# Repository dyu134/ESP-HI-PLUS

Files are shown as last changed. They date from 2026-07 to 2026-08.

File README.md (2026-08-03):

# ESP-HI-PLUS

An **AI-enabled voice assistant with on-screen interaction**, built around the **ESP32-S3-WROOM-1**. The board integrates a microphone, speaker amplifier, IMU, 2" IPS LCD, MicroSD card slot, and USB-C with on-board Li-ion battery charging, and exposes **two 5-pin magnetic pogo-pin connectors** for attaching various sub-modules. Designed for handheld and wearable applications that combine on-device conversational AI, audio capture/playback, display feedback, and motion sensing.

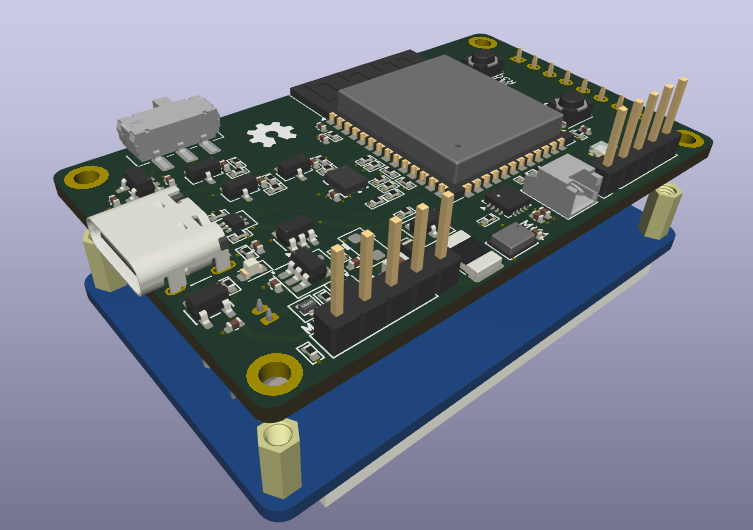
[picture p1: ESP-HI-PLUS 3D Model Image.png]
ESP-HI-PLUS 3D Model


## Features

### Core Compute

- **ESP32-S3-WROOM-1** (U2) — 32-bit dual-core LX7 MCU with Wi-Fi 4, BLE 5 (LE), and a rich peripheral set including I2S, I2C, SPI, and USB.

### Sensors

- **LSM6DSV16X** 6-axis IMU (U8) — 3-axis accelerometer + 3-axis gyroscope with I3C/I2C/SPI interface for motion tracking.
- **ICS-43434 I2S Microphone** (MK1) — digital MEMS microphone over I2S for audio capture.

### Audio Output

- **MAX98357A** Class-D I2S amplifier (U7) — drives an external speaker (LS1) with no required MCLK.
- **PicoBlade speaker connector** (LS1) for an off-board speaker.

### Power

- **USB-C input** (J1) with **USBLC6-2P6** ESD protection (D1/D7/D8).
- **TP4065** linear Li-ion/Li-Po charger (U5) — single-cell charging from USB.
- **TLV75733PDBV** 3.3 V LDO (U3) — system rail for the MCU and logic.
- **MAX40200AUK** ideal-diode OR-ing (U1, U6) — seamless USB / battery switching with low dropout.
- **PicoBlade battery connector** (BT1) for a single-cell Li-ion / Li-Po pack.
- **PMEG4010CEJ** Schottky diode (D5) and **MF-MSMF200** PTC fuse (F1) for input/battery protection.
- **SMF6.8CA** TVS diode (D6) for transient suppression.

### User Interface

- **[2" LCD header](https://www.waveshare.com/2inch-LCD-Module.htm)** (J2) — 2" IPS LCD display.
- **MicroSD Card Slot** (J5) — for local storage of audio, logs, or assets.
- **Two SKRPACE010 tactile pushbuttons** (SW1, SW2).
- **JS102011SAQN SPDT slide switch** (SW3).
- **WS2812B-2020** addressable RGB LED (D12), plus discrete status LEDs (D2 orange for battery charging, D4 red for USB power).
- **Two PR5L4015-5P-C-F magnetic pogo-pin connectors** (J3, J4) — 5-pin 2.54 mm headers that mate with **magnetic pogo-pin sub-modules** for snap-on expansion.

### Mounting

- Four M2 slim mounting holes (H1–H4).

## Sub-Module Identification

The ESP-HI-PLUS uses a two-stage detection system (analog ID resistor + I²C EEPROM metadata) to identify and configure attached sub-modules.

Detailed technical specifications for the identification protocol, class table, and EEPROM metadata can be found in the [Sub-modules directory](./Sub-modules/README.md).

## Available Sub-modules

- **[Desktop](./Sub-modules/Desktop/README.md)** — A desktop alarm clock and environment monitor featuring temperature, humidity, and presence sensing.

See the [Sub-modules directory](./Sub-modules/README.md) for technical specifications and the full list of supported classes.

## Repository Layout

```text
.
├── ESP-HI-PLUS.kicad_pro       # KiCad project file
├── ESP-HI-PLUS.kicad_sch       # Schematic
├── ESP-HI-PLUS.kicad_pcb       # PCB layout
├── Sub-modules/                # Snap-on expansion boards
│   └── Desktop/                # Desktop alarm clock / environment monitor
├── fp-lib-table                # Footprint library table
├── sym-lib-table               # Symbol library table
├── fabrication-toolkit-options.json
├── ESP-HI-PLUS Symbols/        # Project-local schematic symbols
├── ESP-HI-PLUS Footprints/     # Project-local footprint libraries (*.pretty)
├── ESP-HI-PLUS 3D Models/      # STEP models used by the 3D viewer
├── production/                 # Manufacturing outputs
    ├── bom.csv                 # Bill of materials
    ├── designators.csv         # Reference designators
    ├── positions.csv           # Pick-and-place positions
    ├── netlist.ipc             # IPC-D-356 netlist
    └── ESP-HI-PLUS_v1.17.zip   # Production archive (latest)
```

## Bill of Materials (summary)

| Refs | Description |
|---|---|
| U2 | ESP32-S3-WROOM-1 module |
| U3 | TLV75733PDBV — 3.3 V LDO |
| U5 | TP4065 — Li-ion charger |
| MK1 | ICS-43434 I2S microphone |
| U7 | MAX98357A — I2S Class-D amplifier |
| U8 | LSM6DSV16X — 6-axis IMU |
| U1, U6 | MAX40200AUK — ideal diode |
| D1/D7/D8 | USBLC6-2P6 — USB ESD TVS array |
| D12 | WS2812B-2020 — addressable RGB LED |
| J1 | USB-C receptacle |
| J2 | [2" IPS LCD connector](https://www.waveshare.com/2inch-LCD-Module.htm) |
| J3, J4 | Two 5-pin magnetic pogo-pin connectors (PR5L4015-5P-C-F) for sub-modules |
| J5 | MicroSD Card Slot (Hirose DM3AT) |
| SW1, SW2 | SKRPACE010 tactile pushbuttons |
| SW3 | JS102011SAQN SPDT slide switch |
| R28, R29 | 47 kΩ sub-module **AUX1/ID0** detection resistors (0402) — divider used for ADC class lookup |

See `production/bom.csv` for the full BOM with footprints and quantities.

## Getting Started

1. Open `ESP-HI-PLUS.kicad_pro` in KiCad 8 or later.
2. Review the schematic (`ESP-HI-PLUS.kicad_sch`) and PCB (`ESP-HI-PLUS.kicad_pcb`).
3. Re-generate fabrication outputs as needed (Gerbers, drill files, pick-and-place).
4. Flash the ESP32-S3 via the USB-C port using ESP-IDF or Arduino.

## Manufacturing Outputs

The `production/` folder contains ready-to-use outputs for the latest **v1.17** revision:

- **`bom.csv`** — bill of materials for sourcing.
- **`positions.csv`** — pick-and-place rotation/coordinates for SMT assembly.
- **`netlist.ipc`** — IPC-D-356 test netlist.
- **`ESP-HI-PLUS_v1.17.zip`** — full fabrication archive (Gerbers + drill included).

## License

License not specified. Add a `LICENSE` file if you intend to distribute this design.

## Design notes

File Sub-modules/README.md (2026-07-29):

# ESP-HI-PLUS Sub-modules

This directory contains various snap-on expansion boards for the **ESP-HI-PLUS** main board. These modules connect via the two 5-pin magnetic pogo-pin connectors and are automatically detected by the main board.

## List of Sub-modules

- **[Desktop](./Desktop/README.md)** — Desktop alarm clock and environment monitor. Features temperature/humidity sensing and presence detection.
- **[Portable](./Portable/README.MD)** — High-performance expansion board with STM32U5, USB-PD, and battery charging support.
- **[Robot](./Robot/README.md)** — Robotic actuator and sensing platform with RP2040, IMU, fuel gauge, and 4-channel servo control.

## Sub-Module Identification

The two 5-pin magnetic pogo-pin connectors (J3, J4) carry an analog ID line that lets the main board auto-detect **what class of sub-module** is attached before initializing it.

### How it works

1. **On the main board (ESP-HI-PLUS)**, a resistor divider is built around R28 (47 kΩ) and R29 (47 kΩ) tied to the 3.3 V rail and GND. With no sub-module attached, the divider midpoint sits at ~1.65 V (mid-supply) and is fed into an ESP32-S3 ADC channel.
2. **Before initializing any sub-board**, firmware reads that ADC voltage.
3. **On the sub-module**, an additional pull-up resistor `R_ID` is connected between the **AUX1/ID0** line and 3.3 V. The parallel combination with R28 shifts the divider voltage to a value that uniquely identifies the sub-module class.
4. The measured ADC voltage is matched against the table below to select the correct driver/configuration for the attached module.
5. **Once the class is known**, the main board reads the **I²C EEPROM** sitting on the sub-module through the shared I²C bus on the pogo connector. The EEPROM carries module-specific metadata (see below) that the firmware uses to finish initializing that particular sub-board variant correctly.

The two-stage lookup (cheap analog ID + rich digital metadata) lets many different sub-modules share the same physical connector and pinout while still being recognized, configured, and updated individually.

### Class Table

| Class | R_ID (sub-module pull-up) | ADC Voltage (V) | Class Type |
|---:|---:|---:|---|
| 0 | Open (no module) | 1.65 | No module attached |
| 1 | 953 kΩ | 1.63 | Actuator — Servo |
| 2 | 549 kΩ | 1.58 | Actuator — Stepper |
| 3 | 383 kΩ | 1.54 | Sensor — Environmental |
| 4 | 287 kΩ | 1.49 | Sensor — Mechanical |
| 5 | 226 kΩ | 1.43 | Audio — Speaker |
| 6 | 182 kΩ | 1.37 | Audio — Microphone |
| 7 | 154 kΩ | 1.31 | Display — Screen |
| 8 | 130 kΩ | 1.24 | Display — LED |
| 9 | 110 kΩ | 1.17 | Communication — 2.4 G |
| 10 | 95.3 kΩ | 1.11 | Communication — LoRA |
| 11 | 82.5 kΩ | 1.04 | Power — Battery |
| 12 | 71.5 kΩ | 0.97 | Power — Solar |
| 13 | 61.9 kΩ | 0.89 | User Defined 1 |
| 14 | 53.6 kΩ | 0.82 | User Defined 2 |
| 15 | 47.5 kΩ | 0.75 | User Defined 3 |
| 16–31 | — | — | Reserved |

Designing your own sub-module? Pick any standard E24 / E96 `R_ID` value from the table and add it from the ID line to 3.3 V on the sub-board — the main board will detect the class automatically on the next power-up.

### EEPROM metadata

The sub-module's I²C EEPROM exposes at minimum the following fields, which the main board reads via standard I²C reads (typically at the address indicated by the detected class, default `0x50` if unspecified):

| Offset | Size | Field | Description |
|---:|-----:|---|---|
| 0x00 | 4 | Magic Number | ASCII `"ESPM"` (0x45 0x53 0x50 0x4D) — sanity-check that an ESP-HI EEPROM is present |
| 0x04 | 1 | Class ID | Module-class number matching the class table above (little-endian `u8`) |
| 0x05 | 1 | Module ID | Module-class number matching the class table above (little-endian `u8`) |
| 0x06 | 1 | HW revision | Sub-board hardware revision (little-endian `u8`) |
| 0x07 | 2 | FW revision | Sub-board firmware revision (major.minor) (little-endian `u16`) |
| 0x09 | 1 | Protocol revision | Communication protocol revision (little-endian `u8`) |
| 0x0A | 1 | Power requirement | 0x00 = Self-powered, 0x01 = Requires 5V, 0x02 = Can charge |
| 0x0B | 2 | Max Current (mA)  | Maximum current draw (little-endian `u16`), default 500 mA |
| 0x0D | 2 | Min Voltage (mV)  | Minimum supply voltage (little-endian `u16`), default 4500 mV |
| 0x0F | 2 | Boot Delay | Number of milliseconds to delay after power-on (little-endian `u16`), default 100ms  |
| 0x11 | 4 | Capability Bitmask| Bitmask of capabilities defined below (little-endian `u32`) |
| 0x15 | 16 | Module Name | ASCII string (little-endian `u32`) |
| 0x25 | 16 | Serial Number | ASCII string (little-endian `u32`) |
| 0x35 | 198  | User Data | ASCII string (little-endian `u32`) |
| 0xFB | 4 | CRC32 | CRC32 of the rest of the EEPROM data (little-endian `u32`) |

If the magic bytes don't match or the CRC fails, the main board treats the EEPROM as missing/corrupt and falls back to the **class-only driver** selected from the table — letting older or unprogrammed sub-modules still function.

### Capability Bitmask

The 32-bit field at EEPROM offset `0x11` advertises the runtime capabilities of the attached sub-module. Each bit is enumerated below; **bits 8–31 are reserved** for future use and must be written as `0` by sub-module firmware.

| Bit | Name | Meaning |
|----:|---|---|
| 0 | Needs Calibration | Main module must send `CMD_CALIBRATE` before normal ops |
| 1 | Requires ACK | Main module must wait for `ACK` after every command |
| 2 | Asynchronous Data | Module sends unsolicited status reports |
| 3 | Supports Sleep | Module can enter sleep mode |
| 4 | Has Emergency Stop | Module can trigger an emergency stop |
| 5 | Supports OTA | Module can receive firmware updates from main |
| 6 | Has Battery Backup | Module has its own backup battery |
| 7 | Requires Bootloader Mode | Main must enter bootloader mode before firmware update |
| 8–31| Reserved | Reserved — must be `0` |

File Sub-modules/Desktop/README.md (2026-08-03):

# Desktop Sub-module

The **Desktop** sub-module is an environment-sensing and time-keeping expansion board for the **ESP-HI-PLUS**. It transforms the voice assistant into a desktop companion capable of monitoring room conditions and detecting human presence.

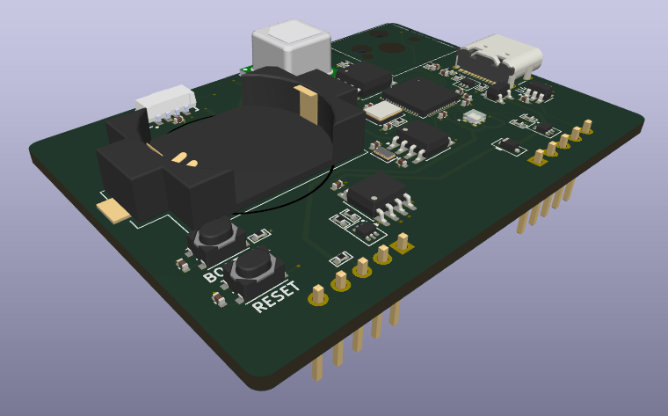
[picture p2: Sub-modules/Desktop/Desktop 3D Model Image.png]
Desktop 3D Model


## Features

### Core Compute

- **RP2040** (U3) — Dual-core ARM Cortex-M0+ microcontroller to handle local sensor processing and timing.
- **16 Mbit Flash** (U1) — Storage for RP2040 firmware.

### Environment Sensors

- **SHT4x** (U5) — High-accuracy relative humidity and temperature sensor.
- **STHS34PF80** (U6) — Infrared sensor for presence and motion detection.
- **VEML7700** (U7) — Ambient light sensor for automatic display brightness adjustment.

### Time Keeping

- **MCP79410** (U8) — I²C Real-Time Clock with SRAM and battery backup.
- **CR2032 Battery** (BT1) — Ensures the clock keeps time even when the main board is powered off.

### Identification & Metadata

The Desktop module follows the standard [ESP-HI-PLUS identification protocol](../README.md).

- **R_ID (383 kΩ)** — Identifies the module as **Class 3 (Sensor — Environmental)**.
- **AT24CS02** (U10) — 2 Kbit I²C EEPROM carrying module metadata and serial number.

#### EEPROM Metadata

| Offset | Size | Field | Value (Hex) | Value (Decoded) | Description |
| :---: | :----: | :--- | :---: | :--- | :--- |
| 0x00 | 4 | Magic Number | 45 53 50 4D | "ESPM" | ASCII sanity check |
| 0x04 | 1 | Class ID | 0x03 | 3 | Sensor - Environmental |
| 0x05 | 1 | Module ID | 0x01 | 1 | Desktop v1.17 |
| 0x06 | 1 | HW Revision | 0x01 | 1 | First PCB revision |
| 0x07 | 2 | FW Revision | 0x1101 | 1.17 | Major.Minor |
| 0x09 | 1 | Protocol Revision | 0x01 | 1 | Communication protocol v1 |
| 0x0A | 1 | Power Requirement | 0x00 | Self-powered | USB-C powered, no V_BUS needed |
| 0x0B | 2 | Max Current (mA) | 0x01F4 | 500 mA | Maximum draw (little-endian) |
| 0x0D | 2 | Min Voltage (mV) | 0x1194 | 4500 mV | Minimum supply voltage (little-endian) |
| 0x0F | 2 | Boot Delay (ms) | 0x0064 | 100 ms | Power-on delay (little-endian) |
| 0x11 | 4 | Capability Bitmask | 0x0000000D | — | Bits 0, 2, 3 enabled (see below) |
| 0x15 | 16 | Module Name | 44 65 73 6B... | "Desktop" | ASCII, null-terminated |
| 0x25 | 16 | Serial Number | 44 43 2D 30... | "DC-001-ABCD" | ASCII, null-terminated |
| 0x35 | 198 | User Data | — | — | Available for custom data |
| 0xFB | 4 | CRC32 | 0xXXXXXXXX | — | CRC32 of bytes 0x00–0xFA |

#### Capability Bitmask

**Value:** `0x0000000D` (Bits 0, 2, and 3 set)

| Bit | Value | Capability | Status |
| :---: | :---: | :--- | :--- |
| 0 | 0x01 | Needs Calibration | ✅ Enabled |
| 1 | 0x02 | Requires ACK | ❌ Disabled |
| 2 | 0x04 | Async Data | ✅ Enabled |
| 3 | 0x08 | Supports Sleep | ✅ Enabled |
| 4 | 0x10 | Has Emergency Stop | ❌ Disabled |
| 5 | 0x20 | Supports OTA | ❌ Disabled |
| 6 | 0x40 | Has Battery Backup | ❌ Disabled |
| 7 | 0x80 | Requires Bootloader Mode | ❌ Disabled |
| 8–31 | — | Reserved | — |

### User Interface & IO

- **WS2812B-2020** (D2) — Addressable RGB LED for status or mood lighting.
- **Tactile Switches** (SW1, SW3) — Reset and bootmode selection switching.
- **Snooze Button** (SW2) — **Kailh MX mechanical keyboard switch** (hotswap) for sleep mode activation.
- **USB-C Port** (J1) — For independent programming and powering of the RP2040.

## Integration

This module identifies itself as an environmental sensor class. The ESP-HI-PLUS main board can read data from the onboard sensors through commands to the RP2040 via UART through the magnetic pogo-pin connectors.

### Pinouts (Magnetic Pogo Connectors)

The Desktop module uses two 5-pin magnetic pogo-pin connectors to interface with the main board.

#### J2 (MAG1)

| Pin | Name | Description |
| --- | --- | --- |
| 1 | VMAIN  | 2-way power bus shared with main module |
| 2 | GND | Ground |
| 3 | UART RX| From main module for data transmission |
| 4 | UART TX| From main module for data transmission |
| 5 | EN | Main module control to enable/disable submodule power |

#### J3 (MAG2)

| Pin | Name | Description |
| --- | --- | --- |
| 1 | I2C SDA  | For reading module ID metadata EEPROM |
| 2 | I2C SCL  | For reading module ID metadata EEPROM |
| 3 | AUX1/ID0 | Hardware class identifier resistor |
| 4 | AUX2 | Auxiliary data pin (unused) |
| 5 | AUX3 | Auxiliary data pin (unused) |

## Repository Layout

```text
.
├── Desktop.kicad_pro           # KiCad project file
├── Desktop.kicad_sch           # Schematic
├── Desktop.kicad_pcb           # PCB layout
├── Desktop Symbols/            # Project-local schematic symbols
├── Desktop Footprints/         # Project-local footprint libraries
├── Desktop 3D Models/          # STEP models
└── production/                 # Manufacturing outputs
    ├── bom.csv                 # Bill of materials
    └── ESP-HI-PLUS_Desktop_Sub-module_v1.17.zip # Production archive (latest)
```

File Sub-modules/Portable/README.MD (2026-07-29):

# Portable Sub-module

The **Portable** sub-module is a high-performance expansion board for the **ESP-HI-PLUS**, designed for mobile use and advanced user interaction. Powered by an STM32U5 series MCU, it provides significant local processing power and support for rich graphical interfaces.

*(Space for 3D Model Image)*

## Features

### Core Compute

- **STM32U5G9VJTxQ** (U1) — High-performance, ultra-low-power ARM Cortex-M33 microcontroller with advanced graphics support and 4 MB of Flash / 3 MB of RAM.

### Power Management

- **TLV75733PDBV** (U4) — 3.3V Low-Dropout (LDO) regulator providing stable power to the MCU and peripherals.
- **TP4065** (U3) — Standalone linear Li-Ion battery charger with thermal regulation.
- **TCPP03-M20** (U2) — USB-PD 3.1 controller with protection for dual-role power (DRP) and over-voltage/current protection.

### Peripherals & IO

- *(Space for Display/LCD additions — DCMI and SPI interfaces available)*
- *(Space for Audio additions — SAI interfaces available)*
- *(Space for Sensor additions)*

### Identification & Metadata

The Portable module follows the standard [ESP-HI-PLUS identification protocol](../README.md).

- **R_ID (383 kΩ)** — Currently identifies the module as **Class 3 (Sensor — Environmental)**. *Note: This may be updated to Class 11 (Power — Battery) or Class 7 (Display) in future revisions.*
- **AT24CS02** (U10) — 2 Kbit I²C EEPROM carrying module metadata and serial number.

#### EEPROM Metadata

| Offset | Size | Field | Value (Hex) | Value (Decoded) | Description |
| :---: | :----: | :--- | :---: | :--- | :--- |
| 0x00 | 4 | Magic Number | 45 53 50 4D | "ESPM" | ASCII sanity check |
| 0x04 | 1 | Class ID | 0x03 | 3 | Sensor - Environmental |
| 0x05 | 1 | Module ID | 0x02 | 2 | Portable v1 |
| 0x06 | 1 | HW Revision | 0x01 | 1 | First PCB revision |
| 0x07 | 2 | FW Revision | 0x0100 | 1.0 | Major.Minor |
| 0x09 | 1 | Protocol Revision | 0x01 | 1 | Communication protocol v1 |
| 0x0A | 1 | Power Requirement | 0x02 | Can charge | (Assumed for Portable) |
| 0x0B | 2 | Max Current (mA) | 0x01F4 | 500 mA | Maximum draw (little-endian) |
| 0x0D | 2 | Min Voltage (mV) | 0x1194 | 4500 mV | Minimum supply voltage (little-endian) |
| 0x0F | 2 | Boot Delay (ms) | 0x0064 | 100 ms | Power-on delay (little-endian) |
| 0x11 | 4 | Capability Bitmask | 0x00000000 | — | TBD |
| 0x15 | 16 | Module Name | 50 6F 72 74... | "Portable" | ASCII, null-terminated |
| 0x25 | 16 | Serial Number | 50 52 2D 30... | "PR-001-XXXX" | ASCII, null-terminated |
| 0x35 | 198 | User Data | — | — | Available for custom data |
| 0xFB | 4 | CRC32 | 0xXXXXXXXX | — | CRC32 of bytes 0x00–0xFA |

#### Capability Bitmask (Proposed)

**Value:** `0x00000000` (TBD)

| Bit | Value | Capability | Status |
| :---: | :---: | :--- | :--- |
| 0 | 0x01 | Needs Calibration | ❌ Disabled |
| 1 | 0x02 | Requires ACK | ✅ Enabled |
| 2 | 0x04 | Async Data | ✅ Enabled |
| 3 | 0x08 | Supports Sleep | ✅ Enabled |
| 4 | 0x10 | Has Emergency Stop | ❌ Disabled |
| 5 | 0x20 | Supports OTA | ✅ Enabled |
| 6 | 0x40 | Has Battery Backup | ✅ Enabled |
| 7 | 0x80 | Requires Bootloader Mode | ❌ Disabled |

## Integration

The Portable module uses the high-performance STM32U5 MCU to handle complex tasks locally. It communicates with the ESP-HI-PLUS main board via UART and I²C.

### Pinouts (Magnetic Pogo Connectors)

#### J2 (MAG1)

| Pin | Name | Description |
| --- | --- | --- |
| 1 | VMAIN  | 2-way power bus shared with main module |
| 2 | GND | Ground |
| 3 | UART RX| Data from main module |
| 4 | UART TX| Data to main module |
| 5 | EN | Main module control to enable/disable submodule power |

#### J3 (MAG2)

| Pin | Name | Description |
| --- | --- | --- |
| 1 | I2C SDA  | For reading module ID metadata EEPROM |
| 2 | I2C SCL  | For reading module ID metadata EEPROM |
| 3 | AUX1/ID0 | Hardware class identifier resistor |
| 4 | AUX2 | Auxiliary data pin |
| 5 | AUX3 | Auxiliary data pin |

## Repository Layout

```text
.
├── Portable.kicad_pro           # KiCad project file
├── Portable.kicad_sch           # Schematic
├── Portable.kicad_pcb           # PCB layout (Initial)
├── Portable-backups/            # Project backups
└── README.md                    # This file
```

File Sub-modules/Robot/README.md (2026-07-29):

# Robot Sub-module

The **Robot** sub-module is a high-performance actuator and sensing expansion board for the **ESP-HI-PLUS**, designed to transform the device into a mobile or interactive robotic platform. Powered by an RP2040 MCU, it handles real-time motor control, battery management, and inertial sensing.

*(Space for 3D Model Image)*

## Features

### Core Compute

- **RP2040** (U3) — Dual-core ARM Cortex-M0+ microcontroller for real-time servo PWM generation and sensor processing.
- **16 Mbit Flash** (U?) — Storage for RP2040 firmware.

### Actuation & Sensing

- **Servo Support** (M1–M4) — High-current outputs for up to 4 high-torque servo motors (e.g., MG996R).
- **LSM6DSV16X** (U8) — 6-axis IMU with embedded sensor fusion and Machine Learning Core for orientation and motion detection.
- **INA3221** (U11) — Triple-channel current and voltage monitor for real-time tracking of servo and system power consumption.

### Power Management

- **TLV75733PDBV** (U4) — 3.3V Low-Dropout (LDO) regulator providing stable power to the MCU and peripherals.
- **MAX17049** (U5) — 2-cell Li-ion battery fuel gauge with ModelGauge m5 algorithm for accurate state-of-charge reporting.
- **MAX40200AUK** (U2) — Ultra-low voltage drop ideal diode for efficient power path management.
- **UBEC Input** — Support for external 5V UBEC to power high-current servos from the battery.
- **XT60 Connector** (J4) — High-current battery interface (typically 2S Li-ion).

### User Interface & IO

- **SK9822-EC20** (D6) — Addressable RGB LED for status or mood lighting.
- **SKRPACE010** (SW3, SW?) — Tactile switches for reset, boot mode, or user interaction.

### Identification & Metadata

The Robot module follows the standard [ESP-HI-PLUS identification protocol](../README.md).

- **R_ID (953 kΩ)** — Identifies the module as **Class 1 (Actuator — Servo)**.
- **AT24CS02** (U10) — 2 Kbit I²C EEPROM carrying module metadata and serial number.

#### EEPROM Metadata

| Offset | Size | Field | Value (Hex) | Value (Decoded) | Description |
| :---: | :----: | :--- | :---: | :--- | :--- |
| 0x00 | 4 | Magic Number | 45 53 50 4D | "ESPM" | ASCII sanity check |
| 0x04 | 1 | Class ID | 0x01 | 1 | Actuator - Servo |
| 0x05 | 1 | Module ID | 0x03 | 3 | Robot v1 |
| 0x06 | 1 | HW Revision | 0x01 | 1 | First PCB revision |
| 0x07 | 2 | FW Revision | 0x0100 | 1.0 | Major.Minor |
| 0x09 | 1 | Protocol Revision | 0x01 | 1 | Communication protocol v1 |
| 0x0A | 1 | Power Requirement | 0x00 | Self-powered | Powered by 2S battery |
| 0x0B | 2 | Max Current (mA) | 0x07D0 | 2000 mA | Maximum draw (little-endian) |
| 0x0D | 2 | Min Voltage (mV) | 0x1770 | 6000 mV | Minimum supply voltage (2S) |
| 0x0F | 2 | Boot Delay (ms) | 0x0064 | 100 ms | Power-on delay (little-endian) |
| 0x11 | 4 | Capability Bitmask | 0x00000014 | — | Bits 2, 4 enabled (Async, E-Stop) |
| 0x15 | 16 | Module Name | 52 6F 62 6F... | "Robot" | ASCII, null-terminated |
| 0x25 | 16 | Serial Number | 52 42 2D 30... | "RB-001-XXXX" | ASCII, null-terminated |
| 0x35 | 198 | User Data | — | — | Available for custom data |
| 0xFB | 4 | CRC32 | 0xXXXXXXXX | — | CRC32 of bytes 0x00–0xFA |

#### Capability Bitmask (Proposed)

**Value:** `0x00000014`

| Bit | Value | Capability | Status |
| :---: | :---: | :--- | :--- |
| 0 | 0x01 | Needs Calibration | ❌ Disabled |
| 1 | 0x02 | Requires ACK | ❌ Disabled |
| 2 | 0x04 | Async Data | ✅ Enabled |
| 3 | 0x08 | Supports Sleep | ❌ Disabled |
| 4 | 0x10 | Has Emergency Stop | ✅ Enabled |
| 5 | 0x20 | Supports OTA | ❌ Disabled |
| 6 | 0x40 | Has Battery Backup | ❌ Disabled |
| 7 | 0x80 | Requires Bootloader Mode | ❌ Disabled |

## Integration

The Robot module uses an RP2040 to handle low-level PWM and sensor data. It communicates with the ESP-HI-PLUS main board via UART and I²C.

### Pinouts (Magnetic Pogo Connectors)

#### J2 (MAG1)

| Pin | Name | Description |
| --- | --- | --- |
| 1 | VMAIN  | 2-way power bus shared with main module |
| 2 | GND | Ground |
| 3 | UART RX| Data from main module |
| 4 | UART TX| Data to main module |
| 5 | EN | Main module control to enable/disable submodule power |

#### J3 (MAG2)

| Pin | Name | Description |
| --- | --- | --- |
| 1 | I2C SDA  | For reading module ID metadata EEPROM |
| 2 | I2C SCL  | For reading module ID metadata EEPROM |
| 3 | AUX1/ID0 | Hardware class identifier resistor |
| 4 | AUX2 | Auxiliary data pin |
| 5 | AUX3 | Auxiliary data pin |

## Repository Layout

```text
.
├── Robot.kicad_pro           # KiCad project file
├── Robot.kicad_sch           # Schematic
├── Robot.kicad_pcb           # PCB layout
├── Robot Symbols/            # Project-local schematic symbols
└── README.md                 # This file
```

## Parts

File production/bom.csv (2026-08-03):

Designator | Footprint | Quantity | Value | LCSC Part #
BT1 | Molex_PicoBlade_53048-0210_1x02_P1.25mm_Horizontal | 1 | Battery_Cell
C1 | 0402 | 1 | 15p
C10, C14, C3, C4, C5, C6 | 0402 | 6 | 10u
C11, C13, C15, C16, C17, C18, C7, C8, C9 | 0402 | 9 | 0u1
C12 | 0805 | 1 | 100u
C19 | 0402 | 1 | 4n7
C2 | 0402 | 1 | 1u
D1, D7, D8 | SOT-666 | 3 | USBLC6-2P6
D10, D11, D9 | SOT-23 | 3 | BAT54S
D12 | LED_WS2812B-2020_PLCC4_2.0x2.0mm | 1 | WS2812B-2020
D2 | 0603 | 1 | ORANGE
D4 | 0603 | 1 | RED
D5 | D_SOD-323F | 1 | PMEG4010CEJ
D6 | D_SOD-123F | 1 | SMF6.8CA
F1 | 1812 | 1 | MF-MSMF200
J1 | USB_C_Receptacle_HCTL_HC-TYPE-C-16P-01A | 1 | USB_C_Receptacle_USB2.0_14P
J2 | PinSocket_1x08_P2.54mm_Vertical | 1 | 2" IPS LCD
J3, J4 | PinHeader_1x05_P2.54mm_Vertical | 2 | PR5L4015-5P-C-F
J5 | microSD_HC_Hirose_DM3AT-SF-PEJM5 | 1 | Micro_SD_Card
LS1 | Molex_PicoBlade_53048-0210_1x02_P1.25mm_Horizontal | 1 | Speaker
MK1 | InvenSense_ICS-43434-6_3.5x2.65mm | 1 | ICS-43434
Q1 | SOT-23 | 1 | AO3401A
Q2 | SOT-723 | 1 | NTK3139P
R1, R13, R2, R30, R31, R32, R33 | 0402 | 7 | 10k
R10, R11, R3, R4, R5, R6 | 0402 | 6 | 5k1
R12, R21, R23, R25, R7 | 0402 | 5 | 100k
R14 | 0402 | 1 | 2k1
R15 | 0402 | 1 | 634k
R17, R18, R19, R20 | 0402 | 4 | 100
R22, R24, R26 | 0402 | 3 | 33k
R27 | 0402 | 1 | 1M
R28, R29 | 0402 | 2 | 47k
R8, R9 | 0402 | 2 | 3k3
SW1, SW2 | SW_Push_1P1T_NO_Vertical_Wuerth_434133025816 | 2 | SKRPACE010
SW3 | SW_SPDT_CK_JS102011SAQN | 1 | JS102011SAQN
U1, U6 | SOT-23-5 | 2 | MAX40200AUK
U2 | ESP32-S3-WROOM-1 | 1 | ESP32-S3-WROOM-1
U3 | SOT-23-5 | 1 | TLV75733PDBV
U5 | SOT-23-5_HandSoldering | 1 | TP4065
U7 | TQFN-16-1EP_3x3mm_P0.5mm_EP1.23x1.23mm | 1 | MAX98357A
U8 | LGA14_LSM6_STM | 1 | LSM6DSV16X

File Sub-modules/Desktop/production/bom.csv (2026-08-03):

Designator | Footprint | Quantity | Value | LCSC Part #
BT1 | BatteryHolder_Keystone_1060_1x2032 | 1 | CR2032
C1, C21, C4, C5 | 0402 | 4 | 1u
C10, C8 | 0402 | 2 | 10u
C11, C12, C15, C16, C17, C18, C19, C2, C20, C9 | 0402 | 10 | 0u1
C13, C14 | 0402 | 2 | 7p
C3 | 0402 | 1 | 4n7
C6, C7 | 0402 | 2 | 15p
D1, D4, D5 | SOT-666 | 3 | USBLC6-2P6
D2 | LED_WS2812B-2020_PLCC4_2.0x2.0mm | 1 | WS2812B-2020
D3 | D_SOD-323F | 1 | PMEG4010CEJ
D6 | 0805 | 1 | RED
D7 | 0805 | 1 | GREEN
J1 | USB_C_Receptacle_HCTL_HC-TYPE-C-16P-01A | 1 | USB_C_Receptacle_USB2.0_14P
J2, J3 | PinHeader_1x05_P2.54mm_Vertical | 2 | PR5L5015-5P-C-H
R1, R7, R8 | 0402 | 3 | 4k7
R10, R11, R12, R9 | 0402 | 4 | 100
R13 | 0402 | 1 | 383k
R14, R15, R4, R5 | 0402 | 4 | 5k1
R2, R6 | 0402 | 2 | 1k
R3 | 0402 | 1 | 1M
SW1, SW3 | SW_Push_1P1T_NO_Vertical_Wuerth_434133025816 | 2 | SKRPACE010
SW2 | SW_Hotswap_Kailh_MX | 1 | SW_Push
U1 | SOIC-8_5.3x5.3mm_P1.27mm | 1 | W25Q16JVSS
U10 | SOIC-8_3.9x4.9mm_P1.27mm | 1 | AT24CS02-SSHM
U2 | SOT-23-5 | 1 | MAX40200AUK
U3 | QFN-56-1EP_7x7mm_P0.4mm_EP3.2x3.2mm | 1 | RP2040
U4 | SOT-23-5 | 1 | TLV75733PDBV
U5 | Sensirion_DFN-4_1.5x1.5mm_P0.8mm_SHT4x_NoCentralPad | 1 | SHT4x
U6 | XDCR_STHS34PF80TR | 1 | STHS34PF80
U7 | VEML7700-TT | 1 | VEML7700-TT
U8 | SOIC-8_3.9x4.9mm_P1.27mm | 1 | MCP79410
Y1 | Crystal_SMD_3225-4Pin_3.2x2.5mm | 1 | ABM8-272-T3
Y2 | Crystal_SMD_2012-2Pin_2.0x1.2mm | 1 | X1A0000610006

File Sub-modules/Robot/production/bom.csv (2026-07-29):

Designator | Footprint | Quantity | Value | LCSC Part #
BT1 | AMASS_XT60-F_1x02_P7.20mm_Vertical | 1 | 2S/10C ~1500mAh
C1 | 0402 | 1 | 4n7
C10, C12, C13, C17, C3, C5, C6, C7 | 0402 | 8 | 0u1
C11, C16, C2, C4 | 0402 | 4 | 1u
C14, C15 | 0402 | 2 | 10u
C8, C9 | 0402 | 2 | 15p
D1 | APA102_2020-6Pin | 1 | SK9822-EC20
D2, D4, D5 | SOT-666 | 3 | USBLC6-2P6
D3 | D_SOD-323F | 1 | PMEG4010CEJ
F1 | 2920 | 1 | 2920L1000SL21GRG
F2, F3, F4, F5 | 1812 | 4 | BSMD1812-200-30V
J1 | USB_C_Receptacle_HCTL_HC-TYPE-C-16P-01A | 1 | USB_C_Receptacle_USB2.0_14P
J2 | JST_XH_S3B-XH-A_1x03_P2.50mm_Horizontal | 1 | JST-XH
J3 | AMASS_XT60PW-M_1x02_P7.20mm_Horizontal | 1 | XT60
J4 | JST_XH_B3B-XH-A_1x03_P2.50mm_Vertical | 1 | JST-XH
J5, J6 | PinHeader_1x05_P2.54mm_Vertical | 2 | PR5L5015-5P-C-H
J7, J8 | Hirose_FH12-10S-0.5SH_1x10-1MP_P0.50mm_Horizontal | 2 | Conn_01x10_MountingPin
M1, M2, M3, M4 | PinHeader_1x03_P2.54mm_Vertical | 4 | MG996R
Q1 | SOT-723 | 1 | NTK3139P
R1 | 0402 | 1 | 1M
R10, R16, R17, R18 | 0402 | 4 | 10k
R11 | 0402 | 1 | 953k
R12, R13, R14, R15 | 0402 | 4 | 100
R2, R5 | 0402 | 2 | 1k
R3, R4 | 0402 | 2 | 5k1
R6, R7 | 0402 | 2 | 4k7
R8 | 1206 | 1 | 5m
R9 | 1206 | 1 | 100m
SW1, SW2 | SW_Push_1P1T_NO_Vertical_Wuerth_434133025816 | 2 | SKRPACE010
U1 | SOIC-8_5.3x5.3mm_P1.27mm | 1 | W25Q16JVSS
U10 | SOIC-8_3.9x4.9mm_P1.27mm | 1 | AT24CS02-SSHM
U2, U5 | SOT-23-5 | 2 | MAX40200AUK
U3 | QFN-56-1EP_7x7mm_P0.4mm_EP3.2x3.2mm | 1 | RP2040
U4 | UBEC-5V | 1 | UBEC-5V
U6 | DFN-8_2x2mm_P0.5mm_EP1.2x0.8mm | 1 | MAX17049
U7 | LGA14_LSM6_STM | 1 | LSM6DSV16X
U8 | SOT-23-5 | 1 | TLV75733PDBV
U9 | Texas_RGV0016A_VQFN-16-1EP_4x4mm_P0.65mm_EP2.1x2.1mm | 1 | INA3221
Y1 | Crystal_SMD_3225-4Pin_3.2x2.5mm | 1 | ABM8-272-T3

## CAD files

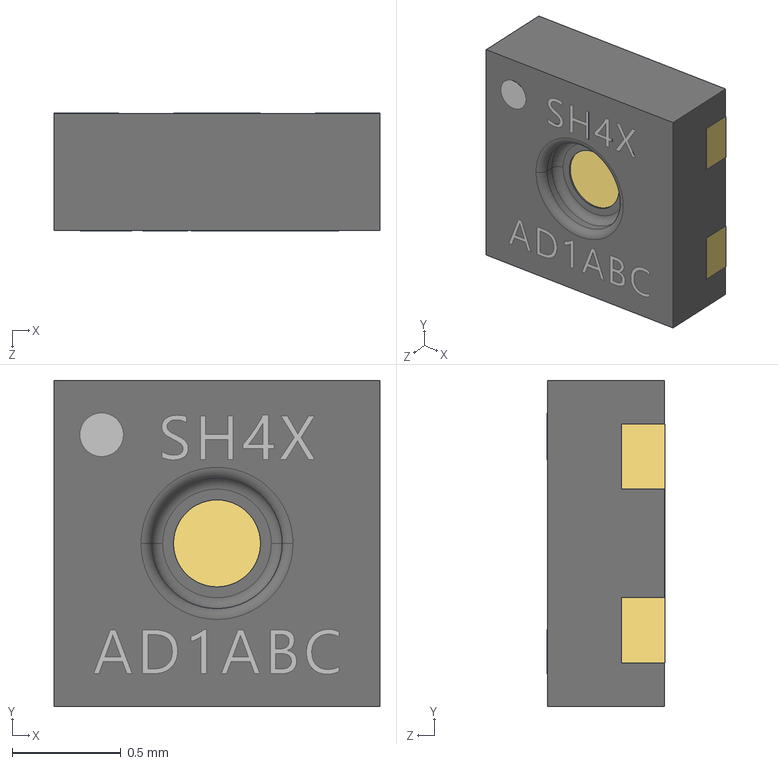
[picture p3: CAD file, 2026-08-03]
Sub-modules/Desktop/Desktop 3D Models/User Library-SHT4X-1.step
1.50 x 1.50 x 0.542 mm

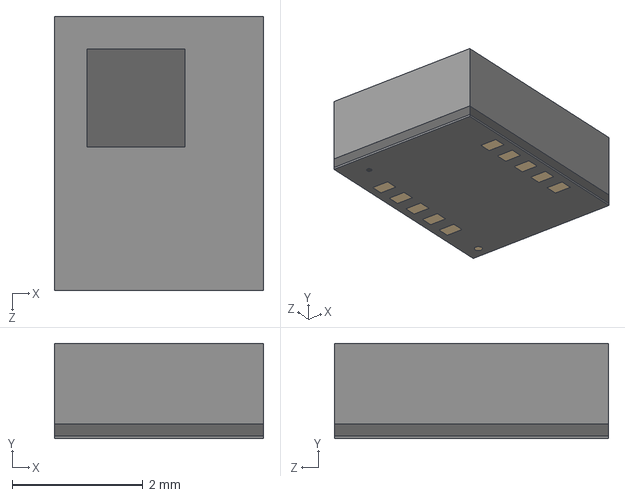
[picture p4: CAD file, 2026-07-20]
Sub-modules/Desktop/Desktop 3D Models/STHS34PF80TR.step
3.20 x 1.46 x 4.20 mm

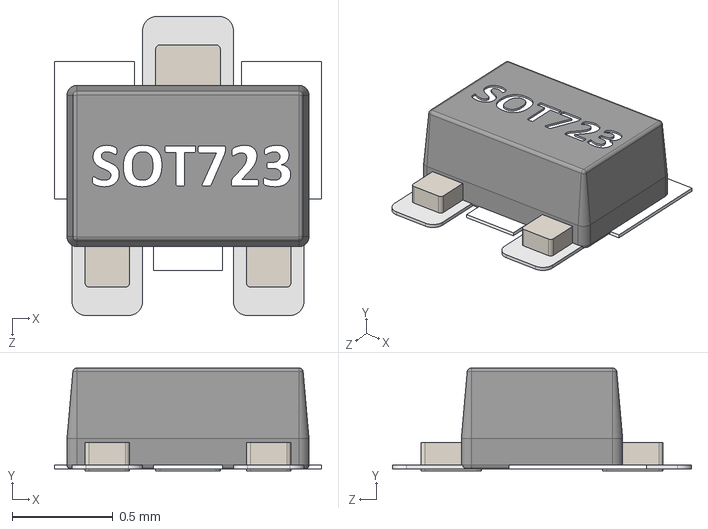
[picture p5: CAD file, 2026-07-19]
ESP-HI-PLUS 3D Models/SOT723.STEP
1.32 x 0.51 x 1.48 mm

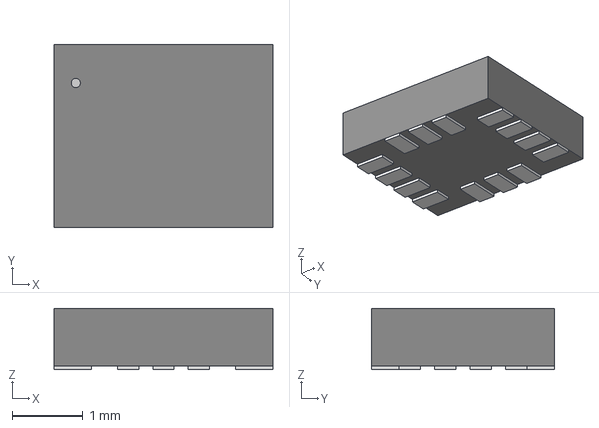
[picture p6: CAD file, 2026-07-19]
ESP-HI-PLUS 3D Models/LGA-14L_STM.step
3.10 x 2.59 x 0.866 mm

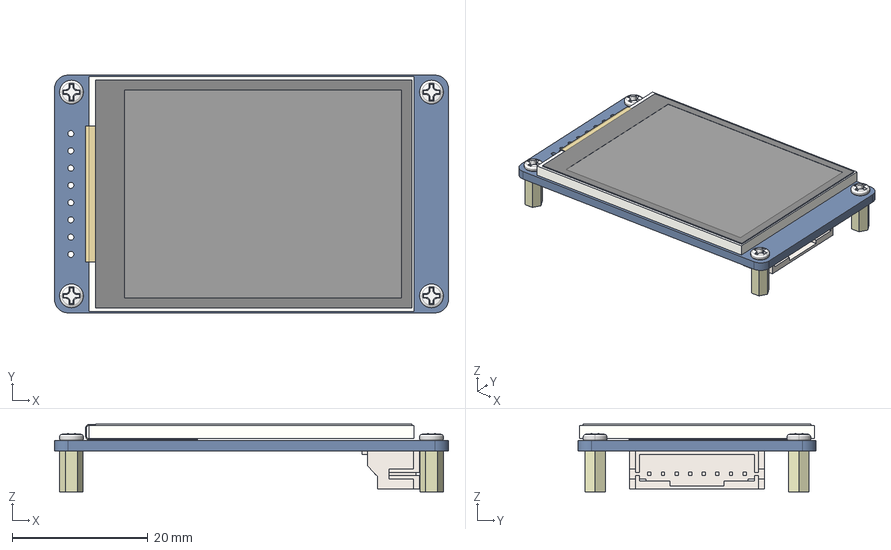
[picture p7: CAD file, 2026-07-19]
ESP-HI-PLUS 3D Models/2inch_LCD_Module_3D_Drawing.stp
58.0 x 35.0 x 10.0 mm
2INCH-240X320-LCD
2INCH-LCD-MODULE-PCBA
HEX_STUDS-M2XH6 x 4
PM2X5-SCREW x 4
HP2_0-8PIN-SMT

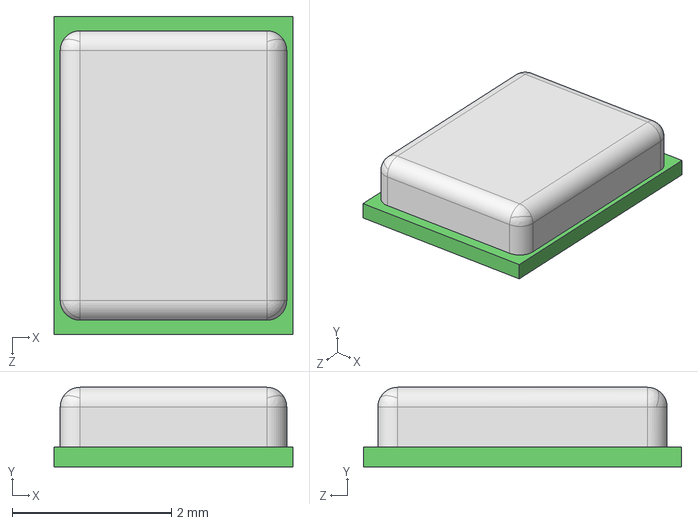
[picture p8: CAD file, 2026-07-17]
ESP-HI-PLUS 3D Models/DMM-4026-B-I2S-R.step
3.00 x 1.00 x 4.00 mm

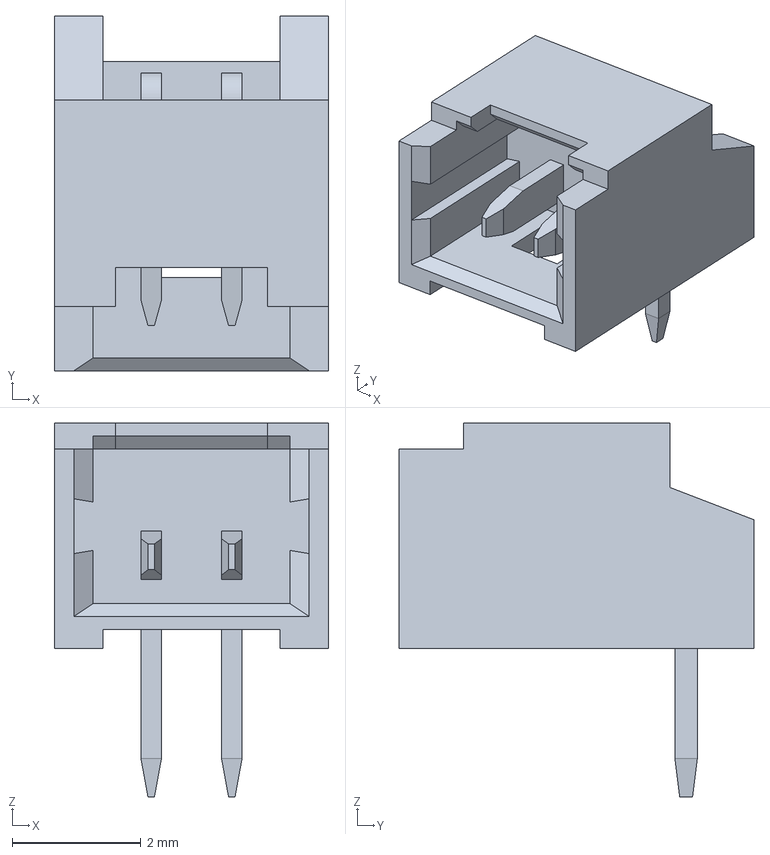
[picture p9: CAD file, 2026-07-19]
ESP-HI-PLUS 3D Models/0530480210.stp
4.25 x 5.50 x 5.80 mm

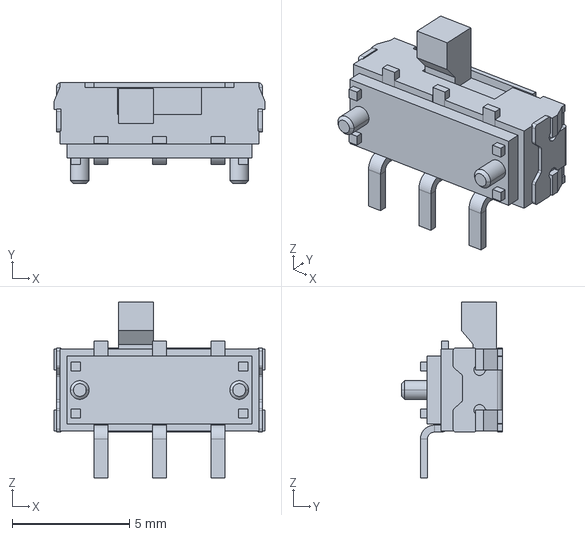
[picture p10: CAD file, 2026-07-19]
ESP-HI-PLUS 3D Models/JS102011SAQN--3DModel-Eagle-1.STEP
9.00 x 4.30 x 7.50 mm

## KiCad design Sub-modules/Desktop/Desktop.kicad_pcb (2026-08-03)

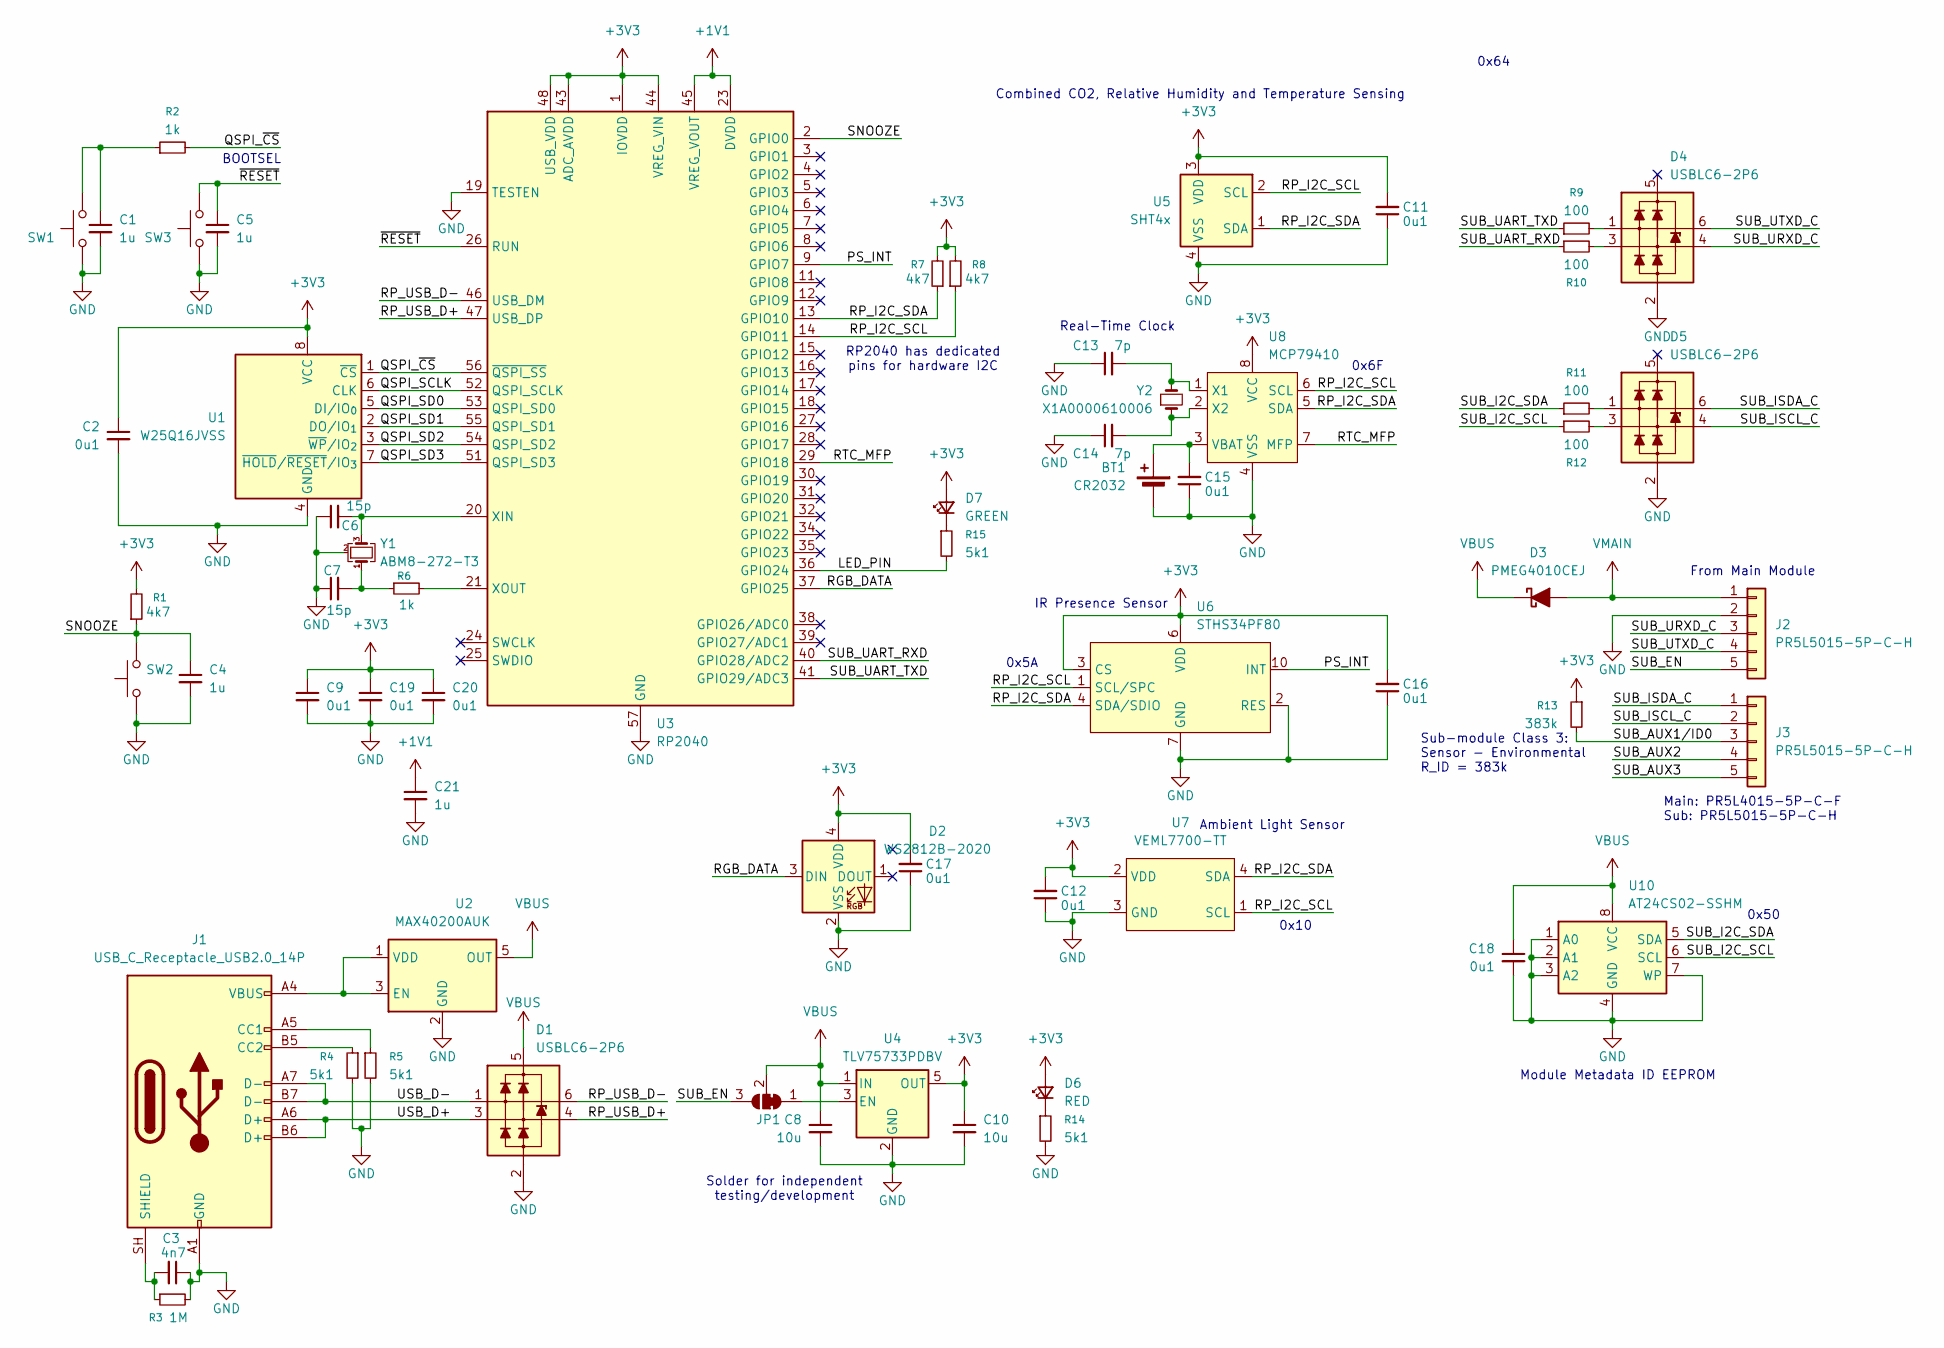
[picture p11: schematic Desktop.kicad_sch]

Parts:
BT1: CR2032; BatteryHolder_Keystone_1060_1x2032
C1, C4, C5, C21: 1u; C_0402_1005Metric
C2, C9, C11, C12, C15, C16, C17, C18, C19, C20: 0u1; C_0402_1005Metric
C3: 4n7; C_0402_1005Metric
C6, C7: 15p; C_0402_1005Metric
C8, C10: 10u; C_0402_1005Metric
C13, C14: 7p; C_0402_1005Metric
D1, D4, D5: USBLC6-2P6; SOT-666
D2: WS2812B-2020; LED_WS2812B-2020_PLCC4_2.0x2.0mm
D3: PMEG4010CEJ; D_SOD-323F
D6: RED; LED_0805_2012Metric
D7: GREEN; LED_0805_2012Metric
J1: USB_C_Receptacle_USB2.0_14P; USB_C_Receptacle_HCTL_HC-TYPE-C-16P-01A
J2, J3: PR5L5015-5P-C-H; PinHeader_1x05_P2.54mm_Vertical
JP1: SolderJumper_3_Bridged12; SolderJumper-3_P1.3mm_Bridged12_RoundedPad1.0x1.5mm
R1, R7, R8: 4k7; R_0402_1005Metric
R2, R6: 1k; R_0402_1005Metric
R3: 1M; R_0402_1005Metric
R4, R5, R14, R15: 5k1; R_0402_1005Metric
R9, R10, R11, R12: 100; R_0402_1005Metric
R13: 383k; R_0402_1005Metric
SW1, SW3: SKRPACE010; SW_Push_1P1T_NO_Vertical_Wuerth_434133025816
SW2: SW_Push; SW_Hotswap_Kailh_MX
U1: W25Q16JVSS; SOIC-8_5.3x5.3mm_P1.27mm
U2: MAX40200AUK; SOT-23-5
U3: RP2040; QFN-56-1EP_7x7mm_P0.4mm_EP3.2x3.2mm
U4: TLV75733PDBV; SOT-23-5
U5: SHT4x; Sensirion_DFN-4_1.5x1.5mm_P0.8mm_SHT4x_NoCentralPad
U6: STHS34PF80; XDCR_STHS34PF80TR
U7: VEML7700-TT
U8: MCP79410; SOIC-8_3.9x4.9mm_P1.27mm
U10: AT24CS02-SSHM; SOIC-8_3.9x4.9mm_P1.27mm
Y1: ABM8-272-T3; Crystal_SMD_3225-4Pin_3.2x2.5mm
Y2: X1A0000610006; Crystal_SMD_2012-2Pin_2.0x1.2mm

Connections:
+1V1: C21.1, U3.23 (DVDD), U3.45 (VREG_VOUT), U3.50 (DVDD)
+3V3: C2.1, C9.1, C10.1, C11.2, C12.2, C16.2, C17.2, C19.1, C20.1, D2.4 (VDD), D6.2 (A), D7.2 (A), R1.2, R7.2, R8.2, R13.1, U1.8 (VCC), U3.1 (IOVDD), U3.10 (IOVDD), U3.22 (IOVDD), U3.33 (IOVDD), U3.42 (IOVDD), U3.43 (ADC_AVDD), U3.44 (VREG_VIN), U3.48 (USB_VDD), U3.49 (IOVDD), U4.5 (OUT), U5.3 (VDD), U6.3 (CS), U6.6 (VDD), U6.9 (VDD), U7.2 (VDD), U8.8 (VCC)
/LED_PIN: R15.2, U3.36 (GPIO24)
/PS_INT: U3.9 (GPIO7), U6.10 (INT)
/QSPI_SCLK: U1.6 (CLK), U3.52 (QSPI_SCLK)
/QSPI_SD0: U1.5 (DI/IO_{0}), U3.53 (QSPI_SD0)
/QSPI_SD1: U1.2 (DO/IO_{1}), U3.55 (QSPI_SD1)
/QSPI_SD2: U1.3 (~WP/IO_{2}), U3.54 (QSPI_SD2)
/QSPI_SD3: U1.7 (~HOLD/~RESET/IO_{3}), U3.51 (QSPI_SD3)
/QSPI_~CS: R2.2, U1.1 (~CS), U3.56 (~QSPI_SS)
/RGB_DATA: D2.3 (DIN), U3.37 (GPIO25)
/RP_I2C_SCL: R8.1, U3.14 (GPIO11), U5.2 (SCL), U6.1 (SCL/SPC), U7.1 (SCL), U8.6 (SCL)
/RP_I2C_SDA: R7.1, U3.13 (GPIO10), U5.1 (SDA), U6.4 (SDA/SDIO), U7.4 (SDA), U8.5 (SDA)
/RP_USB_D+: D1.4 (L2), U3.47 (USB_DP)
/RP_USB_D-: D1.6 (L1), U3.46 (USB_DM)
/RTC_MFP: U3.29 (GPIO18), U8.7 (MFP)
/SNOOZE: C4.1, R1.1, SW2.2, U3.2 (GPIO0)
/SUB_AUX1/ID0: J3.3, R13.2
/SUB_AUX2: J3.4
/SUB_AUX3: J3.5
/SUB_EN: J2.5, JP1.3 (B)
/SUB_I2C_SCL: R12.1, U10.6 (SCL)
/SUB_I2C_SDA: R11.1, U10.5 (SDA)
/SUB_ISCL_C: D5.4 (L2), J3.2
/SUB_ISDA_C: D5.6 (L1), J3.1
/SUB_UART_RXD: R10.1, U3.40 (GPIO28/ADC2)
/SUB_UART_TXD: R9.1, U3.41 (GPIO29/ADC3)
/SUB_URXD_C: D4.4 (L2), J2.3
/SUB_UTXD_C: D4.6 (L1), J2.4
/USB_D+: D1.3 (L2), J1.A6 (D+), J1.B6 (D+)
/USB_D-: D1.1 (L1), J1.A7 (D-), J1.B7 (D-)
/~RESET: C5.1, SW3.2, U3.26 (RUN)
GND: BT1.2 (-), C1.2, C2.2, C3.1, C4.2, C5.2, C6.1, C7.1, C8.2, C9.2, C10.2, C11.1, C12.1, C13.1, C14.1, C15.1, C16.1, C17.1, C18.2, C19.2, C20.2, C21.2, D1.2 (VN), D2.2 (VSS), D4.2 (VN), D5.2 (VN), J1.A1 (GND), J1.A12 (GND), J1.B1 (GND), J1.B12 (GND), J2.2, R3.2, R4.2, R5.2, R14.2, SW1.1, SW2.1, SW3.1, U1.4 (GND), U2.2 (GND), U3.19 (TESTEN), U3.57 (GND), U4.2 (GND), U5.4 (VSS), U6.2 (RES), U6.7 (GND), U6.8 (GND), U7.3 (GND), U8.4 (VSS), U10.1 (A0), U10.2 (A1), U10.3 (A2), U10.4 (GND), U10.7 (WP), Y1.2 (G), Y1.4 (G)
unnamed: BT1.1 (+), C15.2, U8.3 (VBAT)
unnamed: C1.1, R2.1, SW1.2
unnamed: C7.2, R6.1, Y1.1
unnamed: D4.1 (L1), R9.2
unnamed: D4.3 (L2), R10.2
unnamed: D5.1 (L1), R11.2
unnamed: D5.3 (L2), R12.2
unnamed: D6.1 (K), R14.1
unnamed: D7.1 (K), R15.1
unnamed: J1.A5 (CC1), R5.1
unnamed: J1.B5 (CC2), R4.1
unnamed: C3.2, J1.SH (SHIELD), R3.1
unnamed: JP1.1 (A), U4.3 (EN)
unnamed: J1.A4 (VBUS), J1.A9 (VBUS), J1.B4 (VBUS), J1.B9 (VBUS), U2.1 (VDD), U2.3 (EN)
unnamed: C6.2, U3.20 (XIN), Y1.3
unnamed: R6.2, U3.21 (XOUT)
unnamed: C13.2, U8.1 (X1), Y2.2
unnamed: C14.2, U8.2 (X2), Y2.1
VBUS: C8.1, C18.1, D1.5 (VP), D3.1 (K), JP1.2 (C), U2.5 (OUT), U4.1 (IN), U10.8 (VCC)
VMAIN: D3.2 (A), J2.1

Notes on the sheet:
0x64
Ambient Light Sensor
Real-Time Clock
0x5A
IR Presence Sensor
Solder for independent testing/development
Combined CO2, Relative Humidity and Temperature Sensing
0x10
From Main Module
Sub-module Class 3: Sensor - Environmental R_ID = 383k
0x50
Module Metadata ID EEPROM
Main: PR5L4015-5P-C-F Sub: PR5L5015-5P-C-H
0x6F
BOOTSEL
RP2040 has dedicated pins for hardware I2C

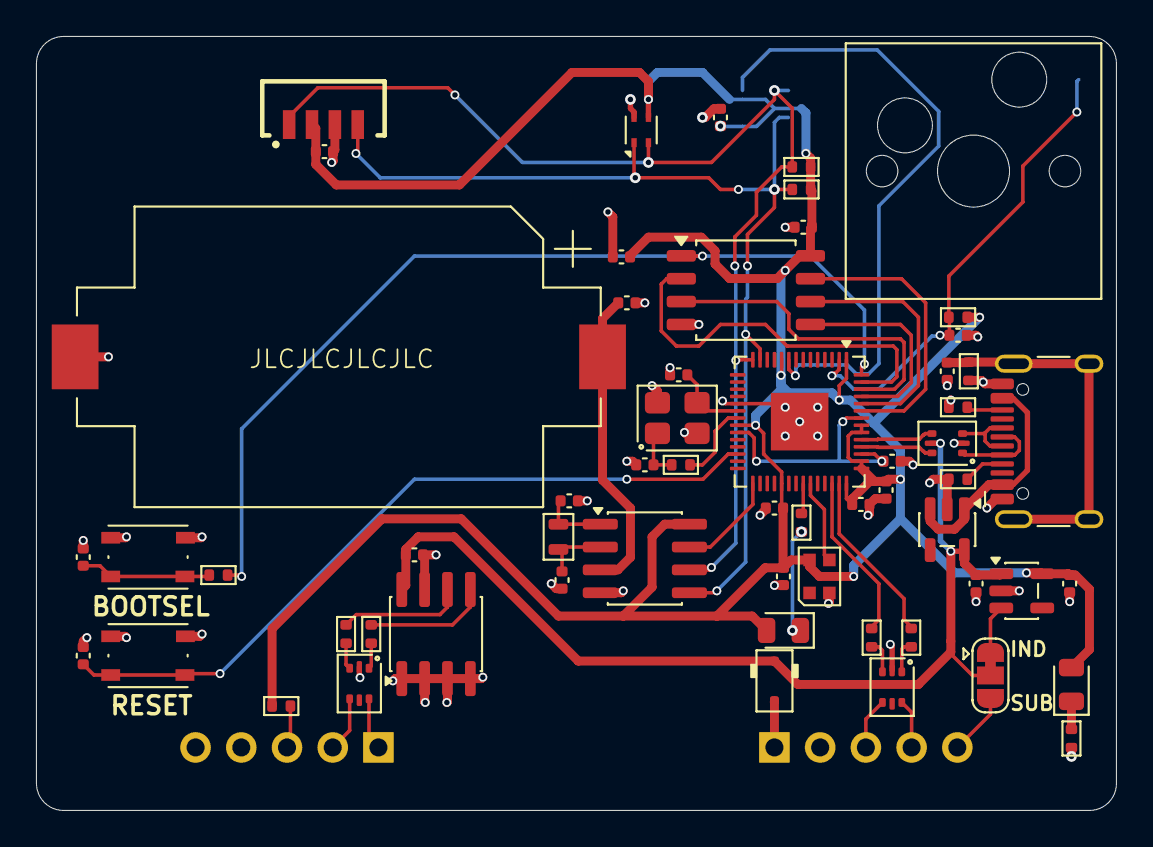
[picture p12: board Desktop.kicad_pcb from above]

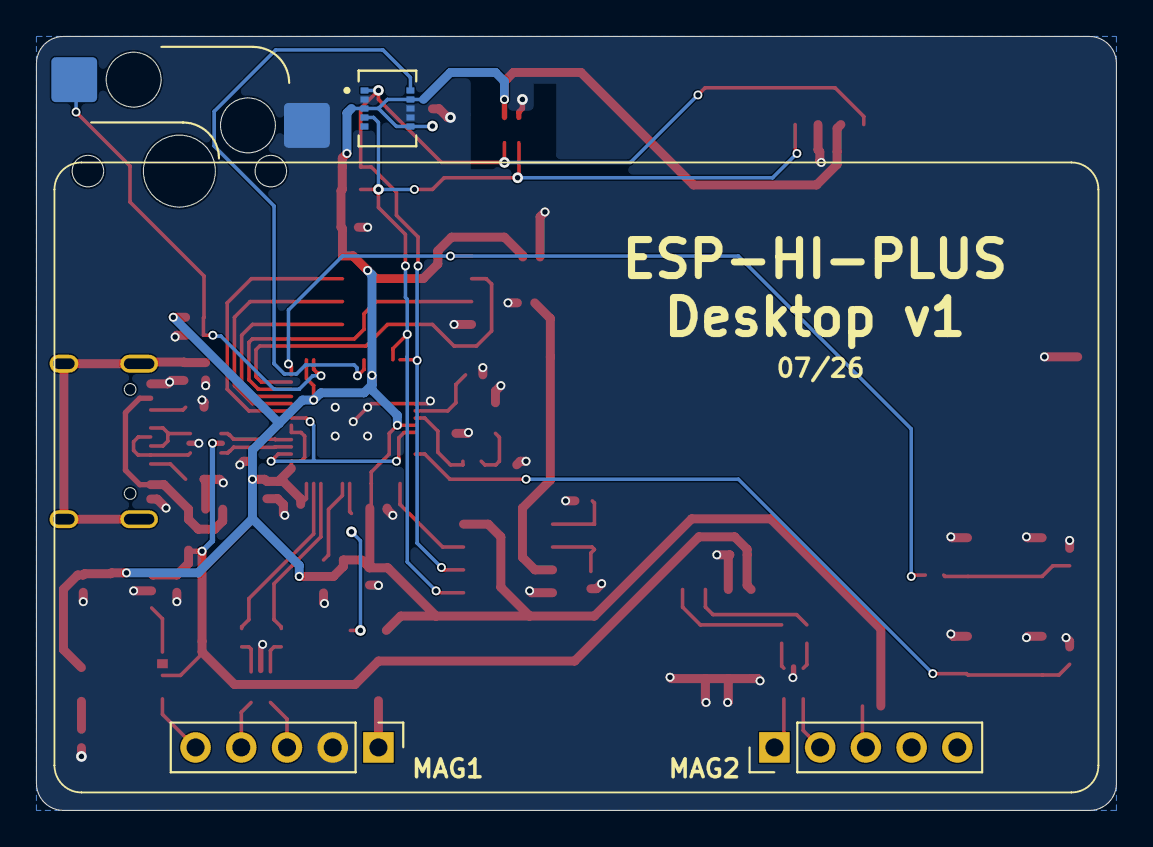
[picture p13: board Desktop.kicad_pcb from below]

Board: 2 copper layers, 60.0 x 43.0 mm, 62 parts (3 on the bottom side), 51 nets.

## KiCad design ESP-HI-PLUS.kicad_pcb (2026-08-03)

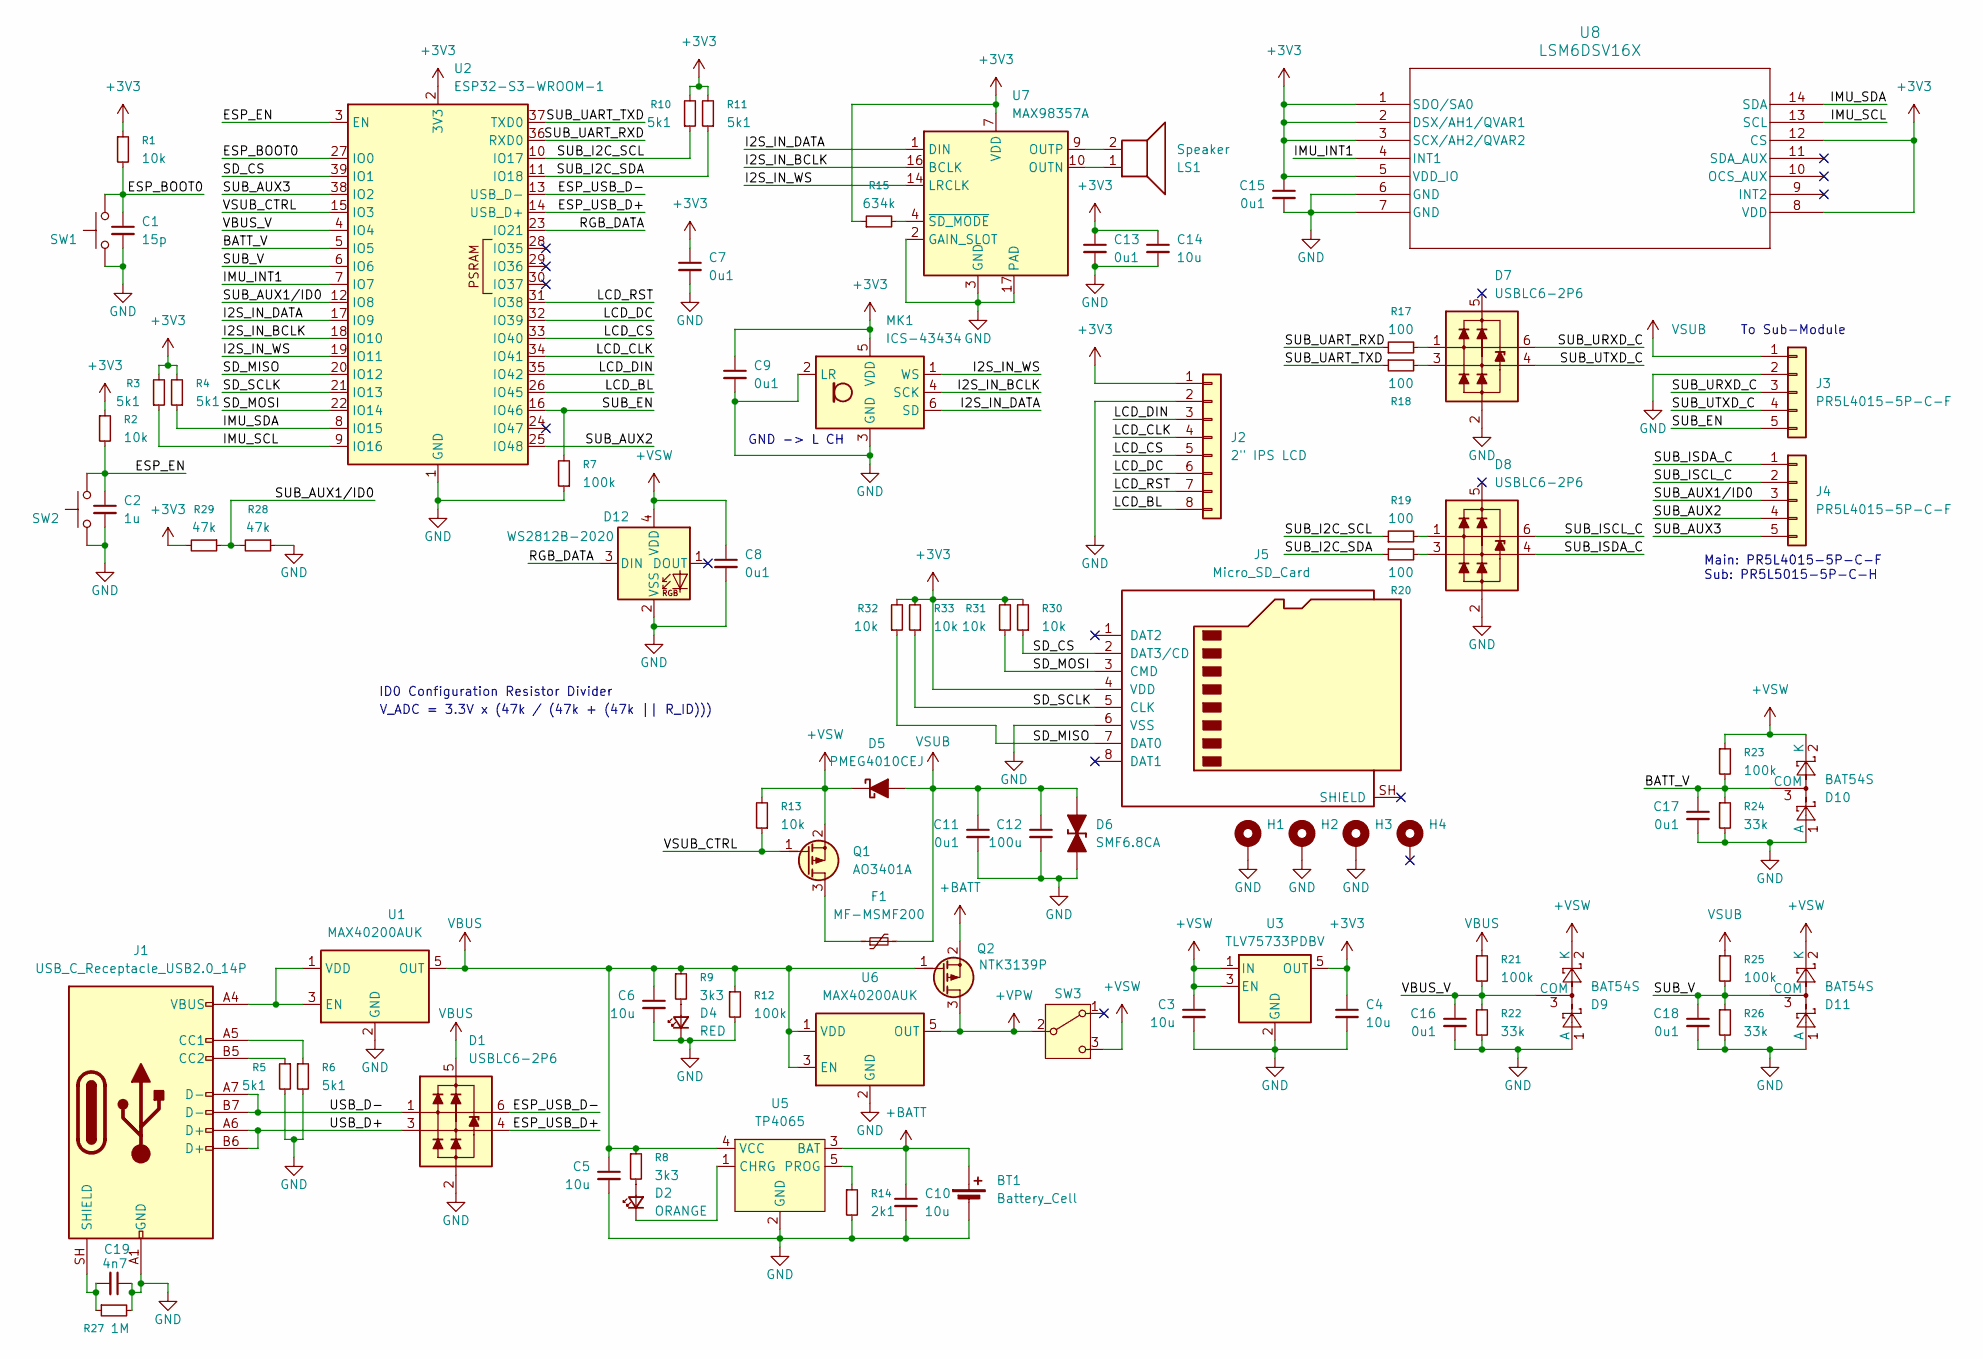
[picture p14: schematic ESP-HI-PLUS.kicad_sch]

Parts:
BT1: Battery_Cell; Molex_PicoBlade_53048-0210_1x02_P1.25mm_Horizontal
C1: 15p; C_0402_1005Metric
C2: 1u; C_0402_1005Metric
C3, C4, C5, C6, C10, C14: 10u; C_0402_1005Metric
C7, C8, C9, C11, C13, C15, C16, C17, C18: 0u1; C_0402_1005Metric
C12: 100u; C_0805_2012Metric
C19: 4n7; C_0402_1005Metric
D1, D7, D8: USBLC6-2P6; SOT-666
D2: ORANGE; LED_0603_1608Metric
D4: RED; LED_0603_1608Metric
D5: PMEG4010CEJ; D_SOD-323F
D6: SMF6.8CA; D_SOD-123F
D9, D10, D11: BAT54S; SOT-23
D12: WS2812B-2020; LED_WS2812B-2020_PLCC4_2.0x2.0mm
F1: MF-MSMF200; Fuse_1812_4532Metric
H1, H2, H3, H4: MountingHole_Pad_MP; MountingHole_M3_Slim
J1: USB_C_Receptacle_USB2.0_14P; USB_C_Receptacle_HCTL_HC-TYPE-C-16P-01A
J2: 2" IPS LCD; PinSocket_1x08_P2.54mm_Vertical
J3, J4: PR5L4015-5P-C-F; PinHeader_1x05_P2.54mm_Vertical
J5: Micro_SD_Card; microSD_HC_Hirose_DM3AT-SF-PEJM5
LS1: Speaker; Molex_PicoBlade_53048-0210_1x02_P1.25mm_Horizontal
MK1: ICS-43434; InvenSense_ICS-43434-6_3.5x2.65mm
Q1: AO3401A; SOT-23
Q2: NTK3139P; SOT-723
R1, R2, R13, R30, R31, R32, R33: 10k; R_0402_1005Metric
R3, R4, R5, R6, R10, R11: 5k1; R_0402_1005Metric
R7, R12, R21, R23, R25: 100k; R_0402_1005Metric
R8, R9: 3k3; R_0402_1005Metric
R14: 2k1; R_0402_1005Metric
R15: 634k; R_0402_1005Metric
R17, R18, R19, R20: 100; R_0402_1005Metric
R22, R24, R26: 33k; R_0402_1005Metric
R27: 1M; R_0402_1005Metric
R28, R29: 47k; R_0402_1005Metric
SW1, SW2: SKRPACE010; SW_Push_1P1T_NO_Vertical_Wuerth_434133025816
SW3: JS102011SAQN; SW_SPDT_CK_JS102011SAQN
U1, U6: MAX40200AUK; SOT-23-5
U2: ESP32-S3-WROOM-1
U3: TLV75733PDBV; SOT-23-5
U5: TP4065; SOT-23-5_HandSoldering
U7: MAX98357A; TQFN-16-1EP_3x3mm_P0.5mm_EP1.23x1.23mm
U8: LSM6DSV16X; LGA14_LSM6_STM

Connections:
+3V3: C4.1, C7.1, C9.1, C13.1, C14.1, C15.1, J2.1, J5.4 (VDD), MK1.5 (VDD), R1.1, R2.1, R3.2, R4.2, R10.2, R11.2, R15.1, R29.2, R30.2, R31.2, R32.2, R33.2, U2.2 (3V3), U3.5 (OUT), U7.7 (VDD), U7.8 (VDD), U8.1 (SDO/SA0), U8.2 (DSX/AH1/QVAR1), U8.3 (SCX/AH2/QVAR2), U8.5 (VDD_IO), U8.8 (VDD), U8.12 (CS)
+BATT: BT1.1 (+), C10.1, Q2.2 (S), U5.3 (BAT)
+VPW: Q2.3 (D), SW3.2 (B), U6.5 (OUT)
+VSW: C3.1, C8.1, D5.1 (K), D9.2 (K), D10.2 (K), D11.2 (K), D12.4 (VDD), Q1.2 (S), R13.2, R23.1, SW3.3 (C), U3.1 (IN), U3.3 (EN)
/BATT_V: C17.1, D10.3 (COM), R23.2, R24.1, U2.5 (IO5)
/ESP_BOOT0: C1.1, R1.2, SW1.2, U2.27 (IO0)
/ESP_EN: C2.1, R2.2, SW2.2, U2.3 (EN)
/ESP_USB_D+: D1.4 (L2), U2.14 (USB_D+)
/ESP_USB_D-: D1.6 (L1), U2.13 (USB_D-)
/I2S_IN_BCLK: MK1.4 (SCK), U2.18 (IO10), U7.16 (BCLK)
/I2S_IN_DATA: MK1.6 (SD), U2.17 (IO9), U7.1 (DIN)
/I2S_IN_WS: MK1.1 (WS), U2.19 (IO11), U7.14 (LRCLK)
/IMU_INT1: U2.7 (IO7), U8.4 (INT1)
/IMU_SCL: R3.1, U2.9 (IO16), U8.13 (SCL)
/IMU_SDA: R4.1, U2.8 (IO15), U8.14 (SDA)
/LCD_BL: J2.8, U2.26 (IO45)
/LCD_CLK: J2.4, U2.34 (IO41)
/LCD_CS: J2.5, U2.33 (IO40)
/LCD_DC: J2.6, U2.32 (IO39)
/LCD_DIN: J2.3, U2.35 (IO42)
/LCD_RST: J2.7, U2.31 (IO38)
/RGB_DATA: D12.3 (DIN), U2.23 (IO21)
/SD_CS: J5.2 (DAT3/CD), R30.1, U2.39 (IO1)
/SD_MISO: J5.7 (DAT0), R32.1, U2.20 (IO12)
/SD_MOSI: J5.3 (CMD), R31.1, U2.22 (IO14)
/SD_SCLK: J5.5 (CLK), R33.1, U2.21 (IO13)
/SUB_AUX1/ID0: J4.3, R28.2, R29.1, U2.12 (IO8)
/SUB_AUX2: J4.4, U2.25 (IO48)
/SUB_AUX3: J4.5, U2.38 (IO2)
/SUB_EN: J3.5, R7.2, U2.16 (IO46)
/SUB_I2C_SCL: R10.1, R19.1, U2.10 (IO17)
/SUB_I2C_SDA: R11.1, R20.1, U2.11 (IO18)
/SUB_ISCL_C: D8.6 (L1), J4.2
/SUB_ISDA_C: D8.4 (L2), J4.1
/SUB_UART_RXD: R17.1, U2.36 (RXD0)
/SUB_UART_TXD: R18.1, U2.37 (TXD0)
/SUB_URXD_C: D7.6 (L1), J3.3
/SUB_UTXD_C: D7.4 (L2), J3.4
/SUB_V: C18.1, D11.3 (COM), R25.2, R26.1, U2.6 (IO6)
/USB_D+: D1.3 (L2), J1.A6 (D+), J1.B6 (D+)
/USB_D-: D1.1 (L1), J1.A7 (D-), J1.B7 (D-)
/VBUS_V: C16.1, D9.3 (COM), R21.2, R22.1, U2.4 (IO4)
/VSUB_CTRL: Q1.1 (G), R13.1, U2.15 (IO3)
GND: BT1.2 (-), C1.2, C2.2, C3.2, C4.2, C5.2, C6.2, C7.2, C8.2, C9.2, C10.2, C11.2, C12.2, C13.2, C14.2, C15.2, C16.2, C17.2, C18.2, C19.1, D1.2 (VN), D4.1 (K), D6.1 (K), D7.2 (VN), D8.2 (VN), D9.1 (A), D10.1 (A), D11.1 (A), D12.2 (VSS), H1.MP (MP_MP), H2.MP (MP_MP), H3.MP (MP_MP), J1.A1 (GND), J1.A12 (GND), J1.B1 (GND), J1.B12 (GND), J2.2, J3.2, J5.6 (VSS), MK1.2 (LR), MK1.3 (GND), R5.2, R6.2, R7.1, R12.2, R14.2, R22.2, R24.2, R26.2, R27.2, R28.1, SW1.1, SW2.1, U1.2 (GND), U2.1 (GND), U2.40 (GND), U2.41 (GND), U3.2 (GND), U5.2 (GND), U6.2 (GND), U7.2 (GAIN_SLOT), U7.3 (GND), U7.11 (GND), U7.15 (GND), U7.17 (PAD), U8.6 (GND), U8.7 (GND)
unnamed: D2.2 (A), R8.2
unnamed: D2.1 (K), U5.1 (CHRG)
unnamed: D4.2 (A), R9.2
unnamed: D7.1 (L1), R17.2
unnamed: D7.3 (L2), R18.2
unnamed: D8.1 (L1), R19.2
unnamed: D8.3 (L2), R20.2
unnamed: J1.A5 (CC1), R6.1
unnamed: J1.B5 (CC2), R5.1
unnamed: C19.2, J1.SH (SHIELD), R27.1
unnamed: F1.1, Q1.3 (D)
unnamed: J1.A4 (VBUS), J1.A9 (VBUS), J1.B4 (VBUS), J1.B9 (VBUS), U1.1 (VDD), U1.3 (EN)
unnamed: R14.1, U5.5 (PROG)
unnamed: LS1.1, U7.10 (OUTN)
unnamed: LS1.2, U7.9 (OUTP)
unnamed: R15.2, U7.4 (~SD_MODE)
VBUS: C5.1, C6.1, D1.5 (VP), Q2.1 (G), R8.1, R9.1, R12.1, R21.1, U1.5 (OUT), U5.4 (VCC), U6.1 (VDD), U6.3 (EN)
VSUB: C11.1, C12.1, D5.2 (A), D6.2 (A), F1.2, J3.1, R25.1

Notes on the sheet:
V_ADC = 3.3V x (47k / (47k + (47k || R_ID)))
GND -> L CH
To Sub-Module
Main: PR5L4015-5P-C-F Sub: PR5L5015-5P-C-H
ID0 Configuration Resistor Divider

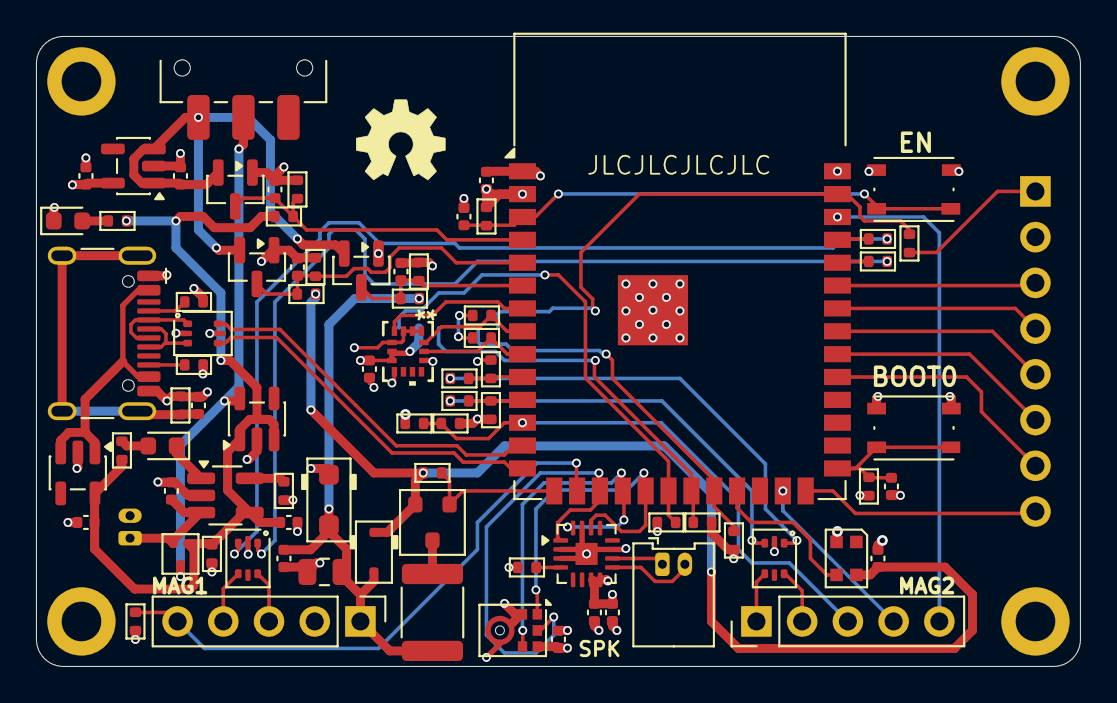
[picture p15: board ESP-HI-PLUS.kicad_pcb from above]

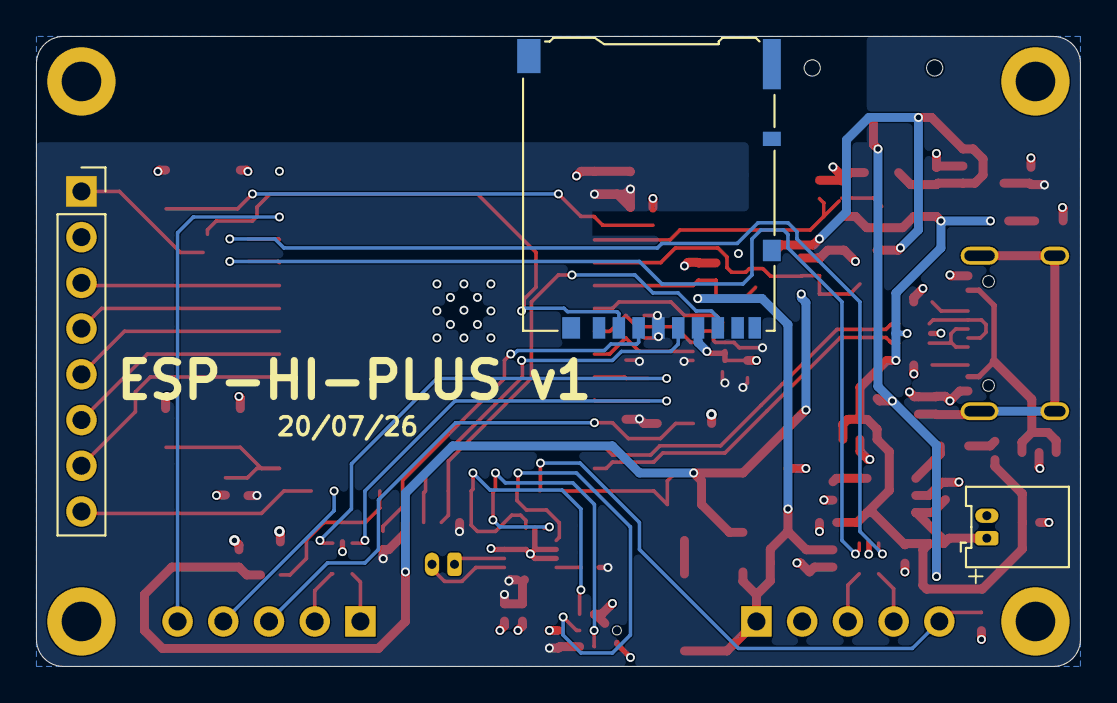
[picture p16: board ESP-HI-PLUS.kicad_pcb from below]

Board: 4 copper layers, 58.0 x 35.0 mm, 88 parts (3 on the bottom side), 62 nets.

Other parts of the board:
Ref**: Val**; OSHW_Logo_5mm

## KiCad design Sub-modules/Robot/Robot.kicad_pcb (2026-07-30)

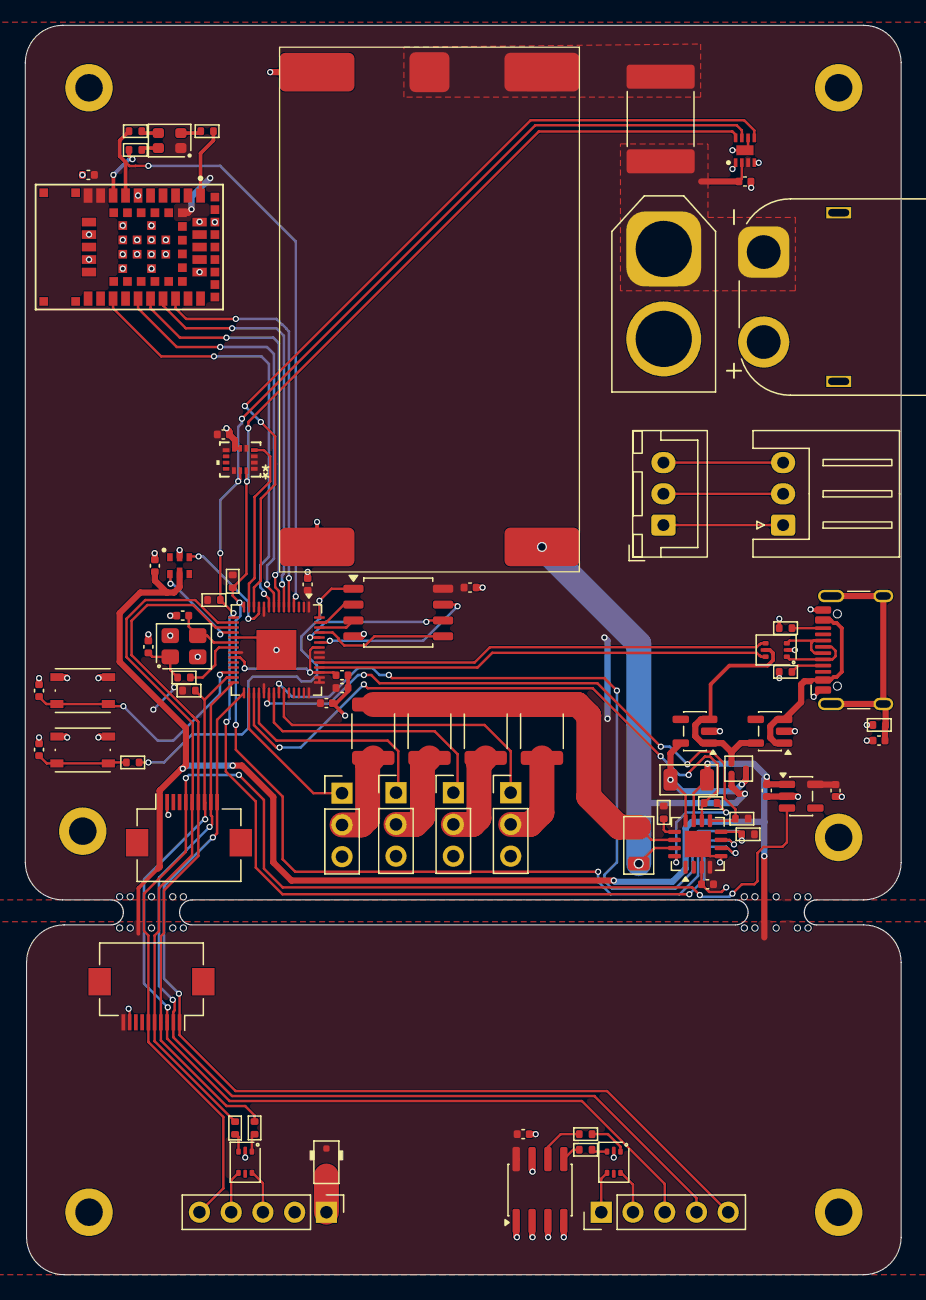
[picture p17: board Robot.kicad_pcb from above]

Board: 2 copper layers, 70.1 x 100.0 mm, 84 parts (0 on the bottom side), 79 nets.

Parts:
BT1: 2S/10C ~1500mAh; AMASS_XT60-F_1x02_P7.20mm_Vertical
C1: 4n7; C_0402_1005Metric
C2, C4, C11, C16: 1u; C_0402_1005Metric
C3, C5, C6, C7, C10, C12, C13, C17, C18: 0u1; C_0402_1005Metric
C8, C9: 15p; C_0402_1005Metric
C14, C15: 10u; C_0402_1005Metric
D1: SK9822-EC20; APA102_2020-6Pin
D2, D4, D5: USBLC6-2P6; SOT-666
D3: PMEG4010CEJ; D_SOD-323F
F1: 2920L1000SL21GRG; Fuse_2920_7451Metric
F2, F3, F4, F5: BSMD1812-200-30V; Fuse_1812_4532Metric
H1, H2, H3, H4, H5, H6: MountingHole_Pad_MP; MountingHole_M3_Slim
J1: USB_C_Receptacle_USB2.0_14P; USB_C_Receptacle_HCTL_HC-TYPE-C-16P-01A
J2: JST-XH; JST_XH_S3B-XH-A_1x03_P2.50mm_Horizontal
J3: XT60; AMASS_XT60PW-M_1x02_P7.20mm_Horizontal
J4: JST-XH; JST_XH_B3B-XH-A_1x03_P2.50mm_Vertical
J5, J6: PR5L5015-5P-C-H; PinHeader_1x05_P2.54mm_Vertical
J7, J8: Conn_01x10_MountingPin; Hirose_FH12-10S-0.5SH_1x10-1MP_P0.50mm_Horizontal
LED1: Broadcom_ASMB-KTF0-0A306; LED_ASMB-KTF0-0A306
M1, M2, M3, M4: MG996R; PinHeader_1x03_P2.54mm_Vertical
Q1: NTK3139P; SOT-723
R1: 1M; R_0402_1005Metric
R2, R5: 1k; R_0402_1005Metric
R3, R4: 5k1; R_0402_1005Metric
R6, R7: 4k7; R_0402_1005Metric
R8: 5m; R_1206_3216Metric
R9: 100m; R_1206_3216Metric
R10, R16, R17, R18: 10k; R_0402_1005Metric
R11: 953k; R_0402_1005Metric
R12, R13, R14, R15: 100; R_0402_1005Metric
R19, R20, R21: 150; R_0402_1005Metric
SW1, SW2: SKRPACE010; SW_Push_1P1T_NO_Vertical_Wuerth_434133025816
U1: W25Q16JVSS; SOIC-8_5.3x5.3mm_P1.27mm
U2, U5: MAX40200AUK; SOT-23-5
U3: RP2040; QFN-56-1EP_7x7mm_P0.4mm_EP3.2x3.2mm
U4: UBEC-5V
U6: MAX17049; DFN-8_2x2mm_P0.5mm_EP1.2x0.8mm
U7: LSM6DSV16X; LGA14_LSM6_STM
U8: TLV75733PDBV; SOT-23-5
U9: INA3221; Texas_RGV0016A_VQFN-16-1EP_4x4mm_P0.65mm_EP2.1x2.1mm
U10: AT24CS02-SSHM; SOIC-8_3.9x4.9mm_P1.27mm
U11: NINA-B416; NINA_LGA71R_1500X1000X223_PCB
Y1: ABM8-272-T3; Crystal_SMD_3225-4Pin_3.2x2.5mm

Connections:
+1V1: C11.1, U3.23 (DVDD), U3.45 (VREG_VOUT), U3.50 (DVDD)
+3V3: C3.1, C6.1, C7.1, C10.1, C13.1, C15.1, C16.1, C18.1, LED1.1 (A), R6.2, R7.2, R11.1, R16.2, R17.2, R18.2, U1.8 (VCC), U3.1 (IOVDD), U3.10 (IOVDD), U3.22 (IOVDD), U3.33 (IOVDD), U3.42 (IOVDD), U3.43 (ADC_AVDD), U3.44 (VREG_VIN), U3.48 (USB_VDD), U3.49 (IOVDD), U6.3 (VDD), U7.1 (SDO/SA0), U7.2 (DSX/AH1/QVAR1), U7.3 (SCX/AH2/QVAR2), U7.5 (VDD_IO), U7.8 (VDD), U7.12 (CS), U8.5 (OUT), U9.4 (VS), U11.9 (VCC_IO), U11.10 (VCC), U11.31 (VBUS)
/BLE_BLUE: R21.2, U11.8 (BLUE)
/BLE_RED: R19.2, U11.1 (RED)
/BLE_SW1: R20.2, U3.4 (GPIO2), U11.7 (GREEN/SWITCH_1)
/BLE_SW2: U3.9 (GPIO7), U11.18 (SWITCH_2)
/BLE_UART_CTS: U3.7 (GPIO5), U11.21 (UART_CTS)
/BLE_UART_RTS: U3.8 (GPIO6), U11.20 (UART_RTS)
/BLE_UART_RX: U3.5 (GPIO3), U11.23 (UART_RXD)
/BLE_UART_TX: U3.6 (GPIO4), U11.22 (UART_TXD)
/CELL1+: J2.1, J4.1
/CELL2-: J2.3, J4.3
/COM: J2.2, J4.2
/IMU_INT1: U3.13 (GPIO10), U7.4 (INT1)
/PWM0: M1.1 (PWM), U3.30 (GPIO19)
/PWM1: M2.1 (PWM), U3.32 (GPIO21)
/PWM2: M3.1 (PWM), U3.35 (GPIO23)
/PWM3: M4.1 (PWM), U3.37 (GPIO25)
/PWR_CRIT: R16.1, U3.34 (GPIO22), U9.9 (CRITICAL)
/PWR_PV: R10.1, U3.31 (GPIO20), U9.10 (PV)
/PWR_TC: R18.1, U9.13 (TC)
/PWR_WARN: R17.1, U3.36 (GPIO24), U9.8 (WARNING)
/PWR_~ALERT: U3.12 (GPIO9), U6.5 (~ALRT)
/QSPI_SCLK: U1.6 (CLK), U3.52 (QSPI_SCLK)
/QSPI_SD0: U1.5 (DI/IO_{0}), U3.53 (QSPI_SD0)
/QSPI_SD1: U1.2 (DO/IO_{1}), U3.55 (QSPI_SD1)
/QSPI_SD2: U1.3 (~WP/IO_{2}), U3.54 (QSPI_SD2)
/QSPI_SD3: U1.7 (~HOLD/~RESET/IO_{3}), U3.51 (QSPI_SD3)
/QSPI_~CS: R2.2, U1.1 (~CS), U3.56 (~QSPI_SS)
/RGB_CLK: D1.4 (CI), U3.18 (GPIO15)
/RGB_DATA: D1.3 (DI), U3.11 (GPIO8)
/RP_I2C_SCL: R7.1, U3.15 (GPIO12), U6.7 (SCL), U7.13 (SCL), U9.6 (SCL)
/RP_I2C_SDA: R6.1, U3.14 (GPIO11), U6.8 (SDA), U7.14 (SDA), U9.7 (SDA)
/RP_USB_D+: D2.4 (L2), U3.47 (USB_DP)
/RP_USB_D-: D2.6 (L1), U3.46 (USB_DM)
/SUB_AUX1/ID0: J6.3, J7.8, J8.3, R11.2, U3.27 (GPIO16)
/SUB_AUX2: J6.4, J7.9, J8.2, U3.28 (GPIO17)
/SUB_AUX3: J6.5, J7.10, J8.1, U3.29 (GPIO18)
/SUB_EN: J5.5, J7.5, J8.6, U8.3 (EN)
/SUB_I2C_SCL: R14.1, U10.6 (SCL)
/SUB_I2C_SDA: R15.1, U10.5 (SDA)
/SUB_ISCL_C: D5.6 (L1), J6.2
/SUB_ISDA_C: D5.4 (L2), J6.1
/SUB_UART_RXD: J7.7, J8.4, R12.1, U3.17 (GPIO14)
/SUB_UART_TXD: J7.6, J8.5, R13.1, U3.16 (GPIO13)
/SUB_URXD_C: D4.6 (L1), J5.3
/SUB_UTXD_C: D4.4 (L2), J5.4
/USB_D+: D2.3 (L2), J1.A6 (D+), J1.B6 (D+)
/USB_D-: D2.1 (L1), J1.A7 (D-), J1.B7 (D-)
/VBATT_MON: Q1.2 (S), R8.1, U4.3 (VOUT), U9.15 (IN+2)
/VBUS_MON: Q1.3 (D), R9.1, U5.5 (OUT), U9.12 (IN+1)
/~RESET: C4.1, SW2.2, U3.26 (RUN)
GND: BT1.2 (-), C1.1, C2.2, C3.2, C4.2, C5.2, C6.2, C7.2, C8.1, C9.1, C10.2, C11.2, C12.2, C13.2, C14.2, C15.2, C16.2, C17.2, C18.2, D1.2 (VSS), D2.2 (VN), D4.2 (VN), D5.2 (VN), H1.MP (MP_MP), H2.MP (MP_MP), H3.MP (MP_MP), H4.MP (MP_MP), H5.MP (MP_MP), H6.MP (MP_MP), J1.A1 (GND), J1.A12 (GND), J1.B1 (GND), J1.B12 (GND), J3.2, J5.2, J7.2, J8.9, M1.3 (-), M2.3 (-), M3.3 (-), M4.3 (-), R1.2, R3.2, R4.2, SW1.1, SW2.1, U1.4 (GND), U2.2 (GND), U3.19 (TESTEN), U3.57 (GND), U4.2 (VIN-), U4.4 (GND), U5.2 (GND), U6.1 (CTG), U6.4 (GND), U6.6 (QSTRT), U6.9 (GND), U7.6 (GND), U7.7 (GND), U8.2 (GND), U9.3 (GND), U9.5 (A0), U9.17 (EP), U10.1 (A0), U10.2 (A1), U10.3 (A2), U10.4 (GND), U10.7 (WP), U11.6 (GND6), U11.12 (GND12), U11.14 (GND14), U11.26 (GND26), U11.30 (GND30), U11.53 (GND53), U11.56 (EGP56), U11.57 (EGP57), U11.58 (EGP58), U11.59 (EGP59), U11.60 (EGP60), U11.61 (EGP61), U11.62 (EGP62), U11.63 (EGP63), U11.64 (EGP64), U11.65 (EGP65), U11.66 (EGP66), U11.67 (EGP67), Y1.2 (G), Y1.4 (G)
unnamed: C2.1, R2.1, SW1.2
unnamed: C9.2, R5.1, Y1.1
unnamed: D4.1 (L1), R12.2
unnamed: D4.3 (L2), R13.2
unnamed: D5.1 (L1), R14.2
unnamed: D5.3 (L2), R15.2
unnamed: J1.A5 (CC1), R4.1
unnamed: J1.B5 (CC2), R3.1
unnamed: C1.2, J1.SH (SHIELD), R1.1
unnamed: LED1.4 (B), R21.1
unnamed: LED1.3 (G), R20.1
unnamed: LED1.2 (R), R19.1
unnamed: F2.2, M1.2 (+)
unnamed: F3.2, M2.2 (+)
unnamed: F4.2, M3.2 (+)
unnamed: F5.2, M4.2 (+)
unnamed: J1.A4 (VBUS), J1.A9 (VBUS), J1.B4 (VBUS), J1.B9 (VBUS), U2.1 (VDD), U2.3 (EN)
unnamed: C8.2, U3.20 (XIN), Y1.3
unnamed: R5.2, U3.21 (XOUT)
unnamed: F1.2, U4.1 (VIN+), U4.5 (EN)
unnamed: R10.2, U9.16 (VPU)
VBATT: BT1.1 (+), C12.1, F1.1, J3.1, U6.2 (CELL)
VBUS: D2.5 (VP), Q1.1 (G), U2.5 (OUT), U5.1 (VDD), U5.3 (EN)
VMAIN: D3.2 (A), J5.1
VSER: F2.1, F3.1, F4.1, F5.1, R8.2, U9.14 (IN-2)
VSYS: C5.1, C14.1, C17.1, D1.5 (VDD), D3.1 (K), J7.1, J8.10, R9.2, U8.1 (IN), U9.11 (IN-1), U10.8 (VCC)

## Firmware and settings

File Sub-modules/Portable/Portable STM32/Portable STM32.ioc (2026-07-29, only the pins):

Mcu.UserName=STM32U5G9VJTxQ
PA0.GPIO_Label=ADC_VBUS
PA0.Signal=ADC1_IN5
PA1.GPIO_Label=TCPP_EN
PA1.Signal=GPIO_Output
PA10.Signal=USB_OTG_HS_ID
PA11.Signal=USB_OTG_HS_DM
PA12.Signal=USB_OTG_HS_DP
PA2.GPIO_Label=TCPP_FLG
PA2.Signal=GPXTI2
PA3.Signal=SAI1_MCLK_A
PA4.Signal=DCMI_HSYNC
PA5.GPIO_Label=ADC_ISENSE
PA5.Signal=ADC1_IN10
PA6.Signal=DCMI_PIXCLK
PA7.Signal=I2C3_SCL
PA8.Signal=SAI1_SCK_A
PA9.Signal=SAI1_FS_A
PB13.Signal=I2C2_SCL
PB14.Signal=I2C2_SDA
PB15.Signal=UCPD1_CC2
PB2.Signal=RTC_OUT2
PB7.Signal=DCMI_VSYNC
PB8.Signal=DCMI_D6
PB9.Signal=DCMI_D7
PC0.Signal=ADC1_IN1
PC1.Signal=SAI1_SD_A
PC10.Signal=USART3_TX
PC11.Signal=USART3_RX
PC13.Signal=RTC_TS
PC2.Signal=USART6_RX
PC3.Signal=USART6_TX
PD3.Signal=DCMI_D5
PH10.Signal=DCMI_D1
PH11.Signal=DCMI_D2
PH12.Signal=DCMI_D3
PH14.Signal=DCMI_D4
PH9.Signal=DCMI_D0
PI1.Signal=SPI2_SCK
PI2.Signal=SPI2_MISO

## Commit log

2026-07-17 update LCD and mounting hole footprints, begin layout
    [1_8inch-lcd-module.dxf, 1_8inch-lcd-module.stp, ESP-HI-PLUS.kicad_pcb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]
2026-07-19 Increase screen size to 2 inch
    [1_8inch-lcd-module.dxf, 1_8inch-lcd-module.stp, 2inch_LCD_Module_3D_Drawing.stp]
2026-07-19 compiled separate symbol and footprint folders
2026-07-19 layout completed
    [ESP-HI-PLUS.kicad_pcb, ESP-HI-PLUS.kicad_sch]
2026-07-19 added 3D models
    [0530480210.stp, DMM-4026-B-I2S-R.step, JS102011SAQN--3DModel-Eagle-1.STEP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]
2026-07-19 added silkscreen and moved reset button to right side
    [ESP-HI-PLUS.kicad_pcb]
2026-07-19 generated fabrication files
    [bom.csv, designators.csv, positions.csv]
2026-07-19 added board image to README
2026-07-20 Added Sub-module Configuration Resistor and Resistor Table
    [ESP-HI-PLUS.kicad_pcb, ESP-HI-PLUS.kicad_sch, bom.csv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]
2026-07-20 Added new Desktop sub-module
    [AHT20.step, Desktop.kicad_pcb, Desktop.kicad_sch]
2026-07-20 Updated layout
    [ESP-HI-PLUS.kicad_pcb]
2026-07-20 Added new Desktop submodule
    [Desktop.kicad_pcb, Desktop.kicad_sch, STHS34PF80TR.step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]
2026-07-20 Added silkscreen
    [Desktop.kicad_pcb]
2026-07-21 ESP-HI-PLUS v1.1: added microSD card slot and combined I2S in/out ports
    [ESP-HI-PLUS.kicad_pcb, ESP-HI-PLUS.kicad_sch, bom.csv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]
2026-07-21 ESP-HI-PLUS v1.15: changed size of 100u capacitor, changed microphone to ICS43434 for availability
    [ESP-HI-PLUS.kicad_pcb, ESP-HI-PLUS.kicad_sch]
2026-07-21 reproduced v1.15 production files
    [ESP-HI-PLUS.kicad_pcb, bom.csv, designators.csv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]
2026-07-21 ESP-HI-PLUS v1.15.1: changed VSUB ESD diode
    [ESP-HI-PLUS.kicad_pcb, ESP-HI-PLUS.kicad_sch, bom.csv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]
2026-07-21 Desktop v1.1: changed CO2 sensor to SCD40 changed location and orientation of presence sensor
    [Desktop.kicad_pcb, Desktop.kicad_sch, bom.csv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]
2026-07-21 Updated README files
    [Desktop.kicad_pcb, SCD4x.step]
2026-07-21 add 70x70 board edge for PCB manufacturing
    [ESP-HI-PLUS.kicad_pcb, designators.csv]
2026-07-23 minor fixes
    [ESP-HI-PLUS.kicad_pcb]
2026-07-23 Desktop v1.15: revert to SHT40 for cost reduction
    [Desktop.kicad_pcb, Desktop.kicad_sch, bom.csv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]
2026-07-26 added Portable submodule
    [Portable.kicad_pcb, Portable.kicad_sch]
2026-07-27 edited Portable submodule, fixed merge conflict
    [ESP-HI-PLUS.kicad_sch, Portable.kicad_sch]
2026-07-28 Setup STM32U5 pinout for Portable submodule
    [ESP-HI-PLUS.kicad_sch, Portable.kicad_sch]
2026-07-29 Added new Robot submodule
    [Robot.kicad_pcb, Robot.kicad_sch]
2026-07-29 fix PCB file corruption
    [ESP-HI-PLUS.kicad_pcb]
2026-07-29 Robot v1.0
    [Robot.kicad_pcb, Robot.kicad_sch, bom.csv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]
2026-07-30 upgrade Robot submodule to 3S battery
    [Robot.kicad_pcb, Robot.kicad_sch]
2026-07-30 added new Keyboard submodule
    [Desktop.kicad_pcb, Desktop.kicad_sch, ESP-HI-PLUS.kicad_pcb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]
2026-07-30 assign footprints to keyswitch and diodes
    [Keyboard.kicad_sch]
2026-08-03 ESP-HI-PLUS v1.17: Changed RGB LED to 2020 NeoPixel
    [ESP-HI-PLUS.kicad_pcb, ESP-HI-PLUS.kicad_sch, bom.csv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]
2026-08-03 Desktop v1.15: Changed I2C pins to 10 and 11 to fix I2C incompatibility issue, changed RGB LED to Neopixel
    [AHT20.step, Desktop.kicad_pcb, Desktop.kicad_sch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]
2026-08-03 updated Portable
    [Portable.kicad_sch]
2026-08-06 updated Keyboard
    [Keyboard.kicad_pcb, Keyboard.kicad_sch]
2026-11-12 Added labeling silkscreen
2026-11-12 swapped PWR_ALERT and PWM0 pins as PWM10 only supports 8-bit while PWM6 on pin PB0 supports 16bit (same as other PWM pins used)
2026-11-12 Changed IMU_INT to PA0 for interrupt capability
